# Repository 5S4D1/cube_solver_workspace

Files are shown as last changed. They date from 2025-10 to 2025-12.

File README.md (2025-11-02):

# Rubik's Cube Solver Robot






An automated Rubik's Cube solving system that uses computer vision for color detection, the Kociemba algorithm for solving, and ROS2 for robot control. The system features a web-based interface for capturing cube faces via camera and real-time solution publishing to hardware controllers.

---

## 📋 Table of Contents

- [Features](#-features)
- [System Architecture](#-system-architecture)
- [Hardware Setup](#-hardware-setup)
- [Project Structure](#-project-structure)
- [Installation](#-installation)
- [Usage](#-usage)
- [API Documentation](#-api-documentation)
- [ROS2 Integration](#-ros2-integration)
- [Development](#-development)
- [Troubleshooting](#-troubleshooting)
- [Contributing](#-contributing)
- [License](#-license)
- [Acknowledgments](#-acknowledgments)

---

## ✨ Features

- **🎥 Computer Vision-Based Detection**
  - HSV-based color detection optimized for cubes with black bases
  - Real-time preview with annotated sticker detection
  - Manual color correction interface

- **🧮 Fast Solving Algorithm**
  - Kociemba two-phase algorithm implementation
  - Optimal or near-optimal solutions (typically 20-25 moves)
  - Validates cube state before solving

- **🌐 Web Interface**
  - Mobile-friendly responsive design
  - Camera access for direct cube capture
  - Face-by-face upload workflow
  - Live solution visualization

- **🤖 ROS2 Integration**
  - Real-time solution publishing to `/cube_solution` topic
  - Compatible with ROS2 Humble and newer
  - Separate hardware control node for robot actuation

- **📊 Project Assets**
  - 3D printable robot parts (STL/STEP files)
  - Project reports and documentation
  - Setup images and diagrams

---

## 🏗️ System Architecture

### Block Diagram

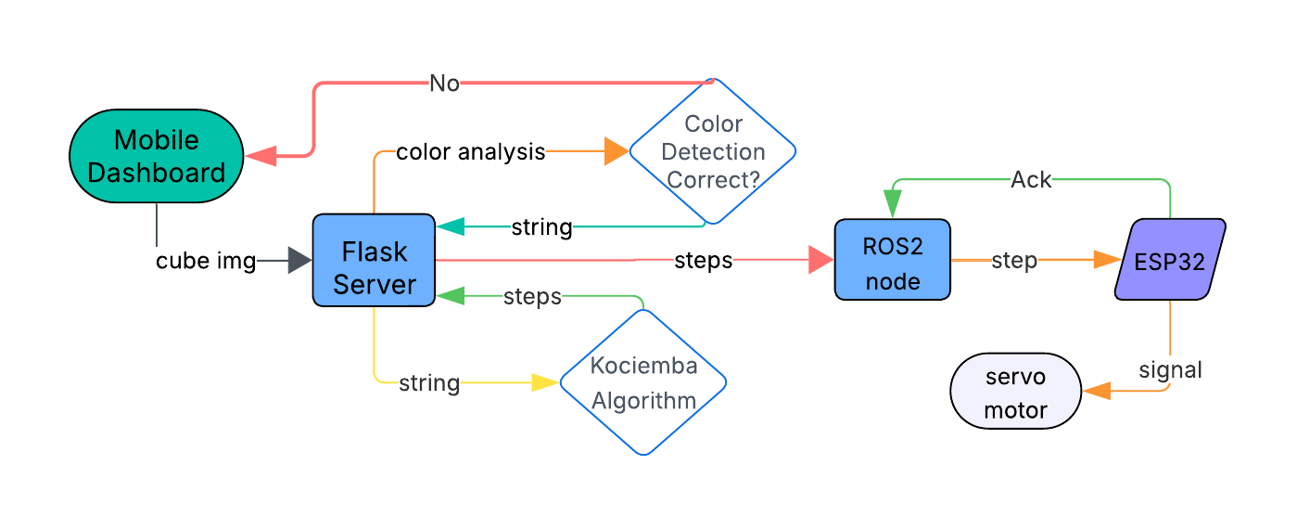
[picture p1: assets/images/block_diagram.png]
System Architecture


### Component Overview

```
┌─────────────────────────────────────────────────────────────┐
│                        Web Browser                          │
│                     (Frontend UI)                           │
│              Camera → Upload → Preview → Solve              │
└────────────────────────┬────────────────────────────────────┘
                         │ HTTPS (Port 5000)
                         ▼
┌─────────────────────────────────────────────────────────────┐
│                    Flask Backend (app.py)                   │
│  ┌──────────────┐  ┌──────────────┐  ┌─────────────────┐  │
│  │   Color      │  │  Kociemba    │  │   ROS2 Bridge   │  │
│  │  Detector    │→ │   Solver     │→ │   Publisher     │  │
│  └──────────────┘  └──────────────┘  └─────────────────┘  │
└────────────────────────────────────────────┬────────────────┘
                                             │ ROS2 Topic
                                             ▼
┌─────────────────────────────────────────────────────────────┐
│              ROS2 /cube_solution Topic                      │
│                   (std_msgs/String)                         │
└────────────────────────────┬────────────────────────────────┘
                             │
                             ▼
┌─────────────────────────────────────────────────────────────┐
│            Hardware Controller Node (Optional)              │
│         Translates moves → Motor commands → Robot           │
└─────────────────────────────────────────────────────────────┘
```

### Technology Stack

| Layer | Technology |
|---|---|
| **Frontend** | HTML5, CSS3, Vanilla JavaScript |
| **Backend** | Python 3.8+, Flask 2.0+ |
| **Computer Vision** | OpenCV, NumPy |
| **Solver** | Kociemba Algorithm (python library) |
| **Middleware** | ROS2 Humble (rclpy, std_msgs) |
| **Hardware** | Arduino (cube_controller firmware) |

---

## 🔧 Hardware Setup

### Physical Setup

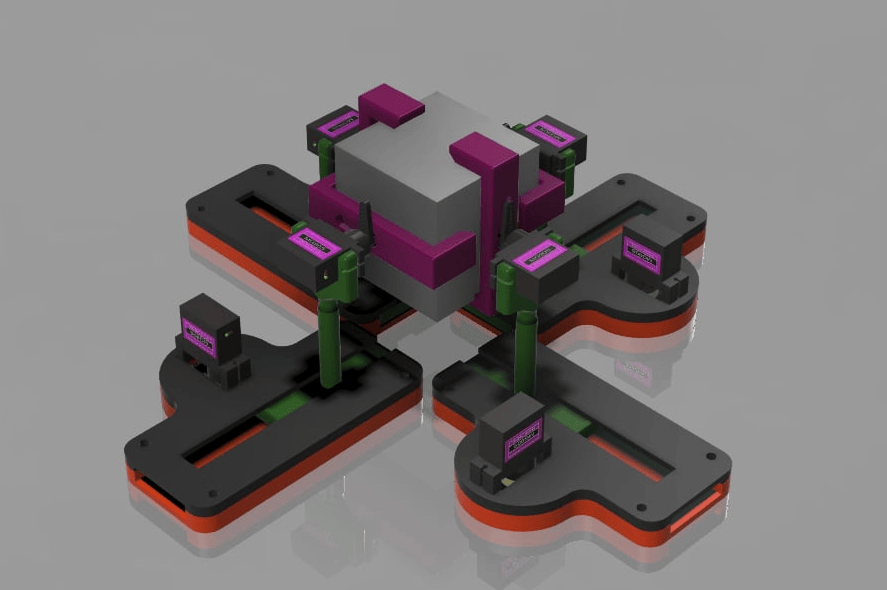
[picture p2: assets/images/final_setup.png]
Final Setup


### Components Required

- **Microcontroller:** Arduino Uno/Mega or compatible board
- **Motors:** 6× Servo motors or stepper motors for face rotation
- **Structure:** 3D-printed frame (files in `assets/3d_parts/`)
- **Camera:** Any USB/built-in camera or smartphone
- **Power Supply:** 5V/12V depending on motor specifications
- **Wiring:** Jumper wires, breadboard, motor drivers (if using steppers)

### 3D Printed Parts

All mechanical parts are available in `assets/3d_parts/`:
- Motor mounts
- Cube holder frame
- Gripper mechanisms
- Base plate

Print settings: 0.2mm layer height, 20% infill, PLA or PETG material.

---

## 📁 Project Structure

```
cube_solver_workspace/
├── assets/                      # Project assets
│   ├── 3d_parts/               # 3D models (STL, STEP)
│   ├── images/                 # Project images and diagrams
│   │   ├── block_diagram.png
│   │   └── final_setup.png
│   └── reports/                # Documentation and reports
├── backend/                     # Flask web server
│   ├── app.py                  # Main Flask application
│   ├── color_detector.py       # Computer vision module
│   ├── kociemba_utils.py       # Cube solver wrapper
│   ├── requirements.txt        # Python dependencies
│   └── uploads/                # Uploaded face images
├── docs/                        # Documentation
│   ├── app.md                  # Backend API documentation
│   ├── color_detector.md       # Color detection module docs
│   ├── kociemba_utils.md       # Solver module docs
│   └── cube_solver_node.md     # ROS2 node documentation
├── firmware/                    # Arduino firmware
│   └── cube_controller/
│       └── cube_controller.ino # Motor control code
├── frontend/                    # Web interface
│   ├── index.html              # Main landing page
│   ├── upload.html             # Face upload interface
│   ├── css/
│   │   └── style.css
│   └── js/
│       └── main.js
├── src/                         # ROS2 package
│   └── cube_solver/
│       ├── package.xml
│       ├── setup.py
│       └── cube_solver/        # ROS2 Python nodes
└── README.md                    # This file
```

---

## 🚀 Installation

### Prerequisites

- **Operating System:** Ubuntu 22.04 (recommended) or compatible Linux
- **Python:** 3.8 or higher
- **ROS2:** Humble Hawksbill or newer
- **Node.js:** Optional (for frontend development tools)

### Step 1: Clone Repository

```bash
git clone https://github.com/5S4D1/cube_solver_workspace.git
cd cube_solver_workspace
```

### Step 2: Install System Dependencies

```bash
# Update system packages
sudo apt update && sudo apt upgrade -y

# Install Python and pip
sudo apt install python3 python3-pip -y

# Install OpenCV dependencies
sudo apt install libopencv-dev python3-opencv -y

# Install ROS2 Humble (if not already installed)
# Follow: https://docs.ros.org/en/humble/Installation.html
```

### Step 3: Install Python Dependencies

```bash
cd backend
pip install -r requirements.txt
```

**requirements.txt includes:**
```
flask>=2.0.0
flask-cors>=3.0.0
kociemba>=1.2.0
opencv-python>=4.5.0
numpy>=1.21.0
pyopenssl>=21.0.0
rclpy
```

### Step 4: Source ROS2 Environment

```bash
source /opt/ros/humble/setup.bash
```

Add to your `~/.bashrc` for persistence:
```bash
echo "source /opt/ros/humble/setup.bash" >> ~/.bashrc
```

### Step 5: Build ROS2 Package (Optional)

If you plan to use the ROS2 subscriber node:

```bash
cd ~/cube_solver_workspace
colcon build --packages-select cube_solver
source install/setup.bash
```

### Step 6: Upload Arduino Firmware (If Using Hardware)

1. Open `firmware/cube_controller/cube_controller.ino` in Arduino IDE
2. Connect your Arduino board
3. Select the correct board and port
4. Upload the firmware

---

## 🎯 Usage

### Quick Start

#### 1. Start the Flask Server

```bash
cd backend
python app.py
```

Server will start at `https://0.0.0.0:5000`

**Note:** HTTPS is required for camera access. You'll see a self-signed certificate warning — accept it to proceed.

#### 2. Access Web Interface

Open your browser and navigate to:
```
https://<your-ip-address>:5000
```

Or on the same machine:
```
https://localhost:5000
```

#### 3. Capture Cube Faces

1. Click "Upload Cube Faces" or navigate to `/upload.html`
2. For each face (U, R, F, D, L, B):
   - Use camera to capture the face
   - Ensure good lighting and center the cube
   - Upload the image
3. Review detected colors (shown with overlays)
4. Manually correct any misdetected colors if needed

#### 4. Solve the Cube

1. Click "Solve Cube" button
2. Backend will:
   - Detect all face colors
   - Validate cube state
   - Compute optimal solution
   - Publish to ROS2 `/cube_solution` topic
3. View solution moves on screen

#### 5. Execute Solution (With Hardware)

If you have the robot hardware connected:
- The solution is automatically published to ROS2
- Your hardware controller node receives the moves
- Robot executes the solution

---

## 📚 API Documentation

### Core Endpoints

| Endpoint | Method | Description |
|---|---|---|
| `/` | GET | Serve main landing page |
| `/upload_face` | POST | Upload single face image |
| `/get_detected_colors?face=U` | GET | Get 3×3 color grid for a face |
| `/solve_cube` | POST | Run full detection → solve → publish pipeline |
| `/manual_solve` | POST | Submit corrected colors or custom cube string |
| `/publish_solution` | POST | Directly solve and publish a cube string |

### Example: Manual Solve with cURL

```bash
curl -X POST https://localhost:5000/manual_solve \
  -H "Content-Type: application/json" \
  -d '{
    "cube_string": "UUUUUUUUURRRRRRRRFFFFFFFFFDDDDDDDDDLLLLLLLLLBBBBBBBBB"
  }'
```

**Response:**
```json
{
  "status": "success",
  "solution": "R U R' U' F2 D B' L2 ..."
}
```

For complete API documentation, see [`docs/app.md`](docs/app.md).

---

## 🤖 ROS2 Integration

### Published Topics

| Topic | Type | Description |
|---|---|---|
| `/cube_solution` | `std_msgs/String` | Solution move sequence (e.g., "R U R' U'") |

### Subscribing to Solutions

Create a simple subscriber:

```python
import rclpy
from rclpy.node import Node
from std_msgs.msg import String

class SolutionListener(Node):
    def __init__(self):
        super().__init__('solution_listener')
        self.subscription = self.create_subscription(
            String,
            '/cube_solution',
            self.solution_callback,
            10)

    def solution_callback(self, msg):
        self.get_logger().info(f'Received solution: {msg.data}')
        # Parse and execute moves here

def main():
    rclpy.init()
    node = SolutionListener()
    rclpy.spin(node)
    node.destroy_node()
    rclpy.shutdown()

if __name__ == '__main__':
    main()
```

Run:
```bash
python3 solution_listener.py
```

For ROS2 node details, see [`docs/cube_solver_node.md`](docs/cube_solver_node.md).

---

## 🛠️ Development

### Running Tests

```bash
# Backend unit tests
cd backend
pytest test_solver.py

# Color detector tests
pytest test_color_detector.py
```

### Adding New Features

1. **Backend:** Add routes to `backend/app.py`
2. **Frontend:** Modify `frontend/index.html` or `frontend/js/main.js`
3. **Computer Vision:** Tune HSV ranges in `backend/color_detector.py`
4. **ROS2:** Add nodes to `src/cube_solver/cube_solver/`

### Logging

Enable debug logging:

```python
import logging
logging.basicConfig(level=logging.DEBUG)
```

Or configure in your application before importing modules:

```python
logging.getLogger('backend.color_detector').setLevel(logging.DEBUG)
```

---

## 🐛 Troubleshooting

### Issue: Camera not accessible in browser

**Solution:** Ensure you're accessing the site via HTTPS (not HTTP). Modern browsers require secure context for camera access.

---

### Issue: "Invalid cube state" error

**Cause:** Detected colors don't form a valid solvable cube.

**Solutions:**
- Check detected colors using annotated `*_detected.jpg` images in `backend/uploads/`
- Improve lighting conditions
- Use manual correction via `/manual_solve` endpoint
- Ensure each color appears exactly 9 times in the 54-sticker cube

---

### Issue: ROS2 topic not receiving messages

**Checklist:**
1. Ensure ROS2 is sourced: `source /opt/ros/humble/setup.bash`
2. Check topic exists: `ros2 topic list`
3. Echo the topic: `ros2 topic echo /cube_solution`
4. Verify Flask backend doesn't show ROS2 errors in console

---

### Issue: Self-signed certificate warnings

**Solution for Development:**
Accept the warning in your browser, or generate a trusted local certificate:

```bash
# Using mkcert (install from https://github.com/FiloSottile/mkcert)
mkcert -install
mkcert localhost 127.0.0.1 ::1
```

Then modify `app.py` to use the generated certificates:
```python
app.run(host='0.0.0.0', port=5000, debug=True, 
        ssl_context=('localhost+2.pem', 'localhost+2-key.pem'))
```

---

### Issue: Colors detected incorrectly (red vs orange, white vs yellow)

**Solutions:**
- Adjust HSV ranges in `color_detector.py` (`HSV_RANGES` dictionary)
- Improve lighting (diffuse white light recommended)
- Ensure cube is centered in frame
- Use manual color correction feature in frontend

See [`docs/color_detector.md`](docs/color_detector.md) for HSV tuning guide.

---

## 📖 Documentation

Detailed documentation for each component:

- **[Backend API (app.py)](docs/app.md)** — Complete API reference, deployment guide
- **[Color Detection (color_detector.py)](docs/color_detector.md)** — Computer vision implementation, HSV tuning
- **[Cube Solver (kociemba_utils.py)](docs/kociemba_utils.md)** — Solver wrapper, algorithm details
- **[ROS2 Node (cube_solver_node)](docs/cube_solver_node.md)** — Hardware integration, node setup

---

## 🤝 Contributing

We welcome contributions! Here's how you can help:

1. **Fork the repository**
2. **Create a feature branch:** `git checkout -b feature/my-new-feature`
3. **Make your changes** and add tests
4. **Update documentation** if needed
5. **Commit your changes:** `git commit -am 'Add new feature'`
6. **Push to the branch:** `git push origin feature/my-new-feature`
7. **Submit a Pull Request**

### Code Style

- **Python:** Follow PEP 8, use `black` formatter
- **JavaScript:** Use ES6+, consistent indentation
- **Documentation:** Update relevant `.md` files in `docs/`

---

## 📄 License

This project is licensed under the MIT License - see the [LICENSE](LICENSE) file for details.

---

## 🙏 Acknowledgments

- **Kociemba Algorithm:** Herbert Kociemba for the two-phase cube solving algorithm
- **Python Kociemba Library:** [kociemba on PyPI](https://pypi.org/project/kociemba/)
- **OpenCV Community:** For computer vision tools and resources
- **ROS2 Community:** For robotics middleware and documentation
- **Contributors:** Thank you to all who have contributed to this project!

---

## 📬 Contact

**Maintainer:** Sadi  
**Email:** shaklinesadi045@gmail.com  
**Repository:** [github.com/5S4D1/cube_solver_workspace](https://github.com/5S4D1/cube_solver_workspace)

---

## 🔗 Quick Links

- [Installation Guide](#-installation)
- [Usage Instructions](#-usage)
- [API Documentation](docs/app.md)
- [Troubleshooting](#-troubleshooting)
- [3D Parts](assets/3d_parts/)
- [Project Reports](assets/reports/)

---

**⭐ If you find this project useful, please star the repository!**

---

*Last Updated: November 2025*

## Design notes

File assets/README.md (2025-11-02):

Project assets

This folder holds project assets used by the frontend and for project delivery.

Structure

- 3d_parts/   - Store 3D design files STL format. Keep original source files here.
- reports/    - Store project reports, PDFs, and documentation artifacts.
- images/     - Store images used in the project and documentation.

Guidelines

- Prefer descriptive filenames: e.g. `clamp.stl`, `Rubik_s_Cube.pdf`, `block_diagram.png`.

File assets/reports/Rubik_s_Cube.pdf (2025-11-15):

3×3 Rubik’s Cube Solver Using Computer Vision,

# ROS2 and ESP32 Controlled Mechanism

Md. Sheikh Sadi
Computer Science and Engineering United International University Dhaka, Bangladesh
msadi223646@bscse.uiu.ac.bd

Badhon Dalbot
Computer Science and Engineering United International University Dhaka, Bangladesh
bdalbot223660@bscse.uiu.ac.bd

Mominul Islam
Computer Science and Engineering United International University Dhaka, Bangladesh
mislam223425@bscse.uiu.ac.bd

Sayed Hasan Sami
Computer Science and Engineering United International University Dhaka, Bangladesh
ssami2230939@bscse.uiu.ac.bd

Md. Mahmud Hasan
Computer Science and Engineering United International University Dhaka, Bangladesh
mhasan2230995@bscse.uiu.ac.bd

Abstract—This paper presents an automated system for solving a standard 3×3 Rubik’s Cube using a combination of computer vision, robotics middleware and a custom mechanical mechanism. The system captures cube face colors with a mobile/web interface, computes an optimal solution using the Kociemba algorithm, and actuates eight servo motors via an ESP32 to manipulate the cube-all coordinated via ROS2. Experimental results demonstrate complete cube solves within ∼96 s, with 98% color detection accuracy in various lighting conditions.
Index Terms—Rubik’s Cube solver, ROS2, ESP32, computer vision, 3D printed mechanism, Kociemba algorithm
I. INTRODUCTION
Problem Statement. Solving a 3×3 Rubik’s Cube quickly and automatically remains a challenging task that combines computer vision, planning algorithms and precise robotic manipulation. Manual solving is accessible, but reliable automation requires robust color detection, efficient solution computation and well-synchronized actuation. Literature Review. Prior work includes robotic cube solvers using stepper motors and simple webcam setups [1], [2]. Some systems rely on dedicated microcontrollers and proprietary drivers [3]. These often trade off modularity or network-based control in favor of pure hardware speed. Innovative features added to our project. Our implementation integrates a mobile/web front-end (for image capture) with the ROS2 middleware, enabling the cube to be manipulated via a publish-subscribe architecture. We also employ an ESP32 controlling eight MG90 servo motors and a fully 3D-printed rack & clamp mechanism-offering cost-effective, scalable hardware.

II. PROPOSED METHOD
A. Block diagram of the overall system
The system comprises three major layers: the user interface (mobile or web), the backend computing & ROS2 broker,

The project was carried out as part of the microprocessor & microcontroller lab course requirement in the Department of Computer Science and Engineering at United International University.

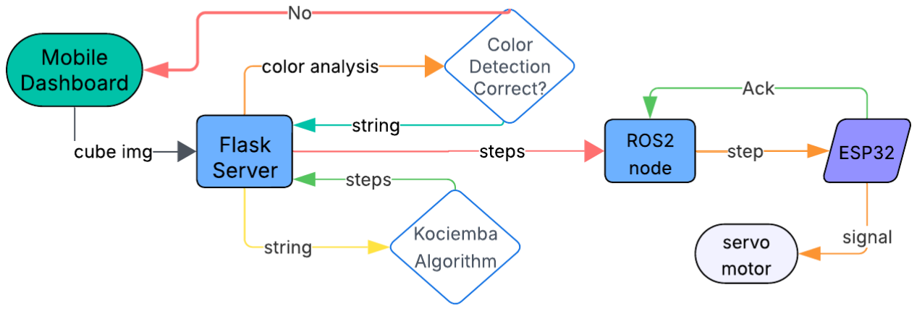
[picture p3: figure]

Fig. 1. Block diagram of the automated cube solving system.

and the mechanical actuation layer. The UI captures six cube faces, the backend uses OpenCV to detect sticker colors and computes a solution via the Kociemba algorithm. That solution is published on a ROS2 topic, subscribed by a node running on a laptop. The laptop forwards individual moves serially to the ESP32, which triggers eight servo motors to manipulate the cube via a 3D-printed rack, clamp and gear system.

III. IMPLEMENTED HARDWARE SYSTEM

A. List of the hardware and software environment

Hardware: ESP32 microcontroller, eight MG90S 9 g servo motors, 3 D-printed parts including rack, rack top, clamp, rack base and spur gear assembly, standard 3×3 Rubik’s Cube. Software: Ubuntu 22.04 LTS with ROS2 Humble, Python 3.13, Flask (backend), OpenCV, Kociemba cube solver library, Web frontend using HTML, CSS, JavaScript.

B. Figures of the implemented hardware system
C. Configure Tables

Table I presents the hardware specifications used in the project, while Table II shows the HSV color detection thresholds used to identify each sticker color during cube face recognition.

Fig. 2. Left: rack. Center: servo holder Right: clamp cube holder.

Fig. 3. Left: rack top. Center: rack base. Right: spur gear

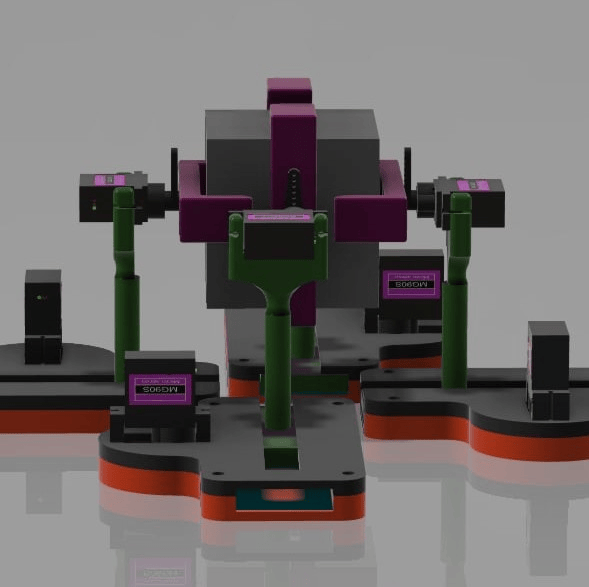
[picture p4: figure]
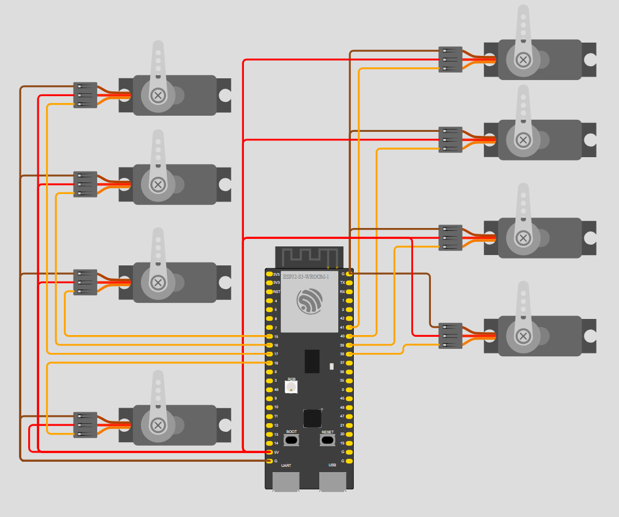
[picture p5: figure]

Fig. 4. Left: MG90S servo mounted on position. Right: ESP32 and wiring interface.


Fig. 5. final setup

TABLE I
SERVO MOTOR AND HARDWARE SPECIFICATIONS
Component | Specification | Value
Servo Type | MG90S Micro-Servo | 9 g, 180◦ range
Microcontroller | ESP32 | Dual-core, WiFi/Bluetooth
3D Printed Parts | Material | PLA+, custom rack, spur and clamp design

TABLE II
HSV COLOR DETECTION RANGES FOR EACH CUBE FACE
Side / Color | Lower HSV Range | Upper HSV Range
White | (0, 0, 120) | (180, 50, 255)
Yellow | (20, 50, 80) | (35, 255, 255)
Red (1) | (0, 120, 120) | (8, 255, 255)
Red (2) | (165, 120, 120) | (180, 255, 255)
Orange | (8, 100, 100) | (25, 255, 255)
Green | (40, 50, 50) | (85, 255, 255)
Blue | (90, 50, 50) | (130, 255, 255)
Black | (0, 0, 0) | (180, 255, 80)

The HSV values in Table II were calibrated manually under controlled lighting conditions. The ranges allow reliable separation of similar hues (e.g., red and orange) and maintain stability across different brightness levels.

IV. RESULTS

The system was evaluated by capturing 20 random cube configurations under varying lighting and executing the full solve sequence. Color detection achieved an average accuracy of 98.2%, and the full mechanical solve completed in 85-110 s depending on re-grip frequency. Table III summarizes the key performance metrics.

TABLE III
PERFORMANCE SUMMARY OF RUBIK’S CUBE SOLVER
Metric | Result
Average Color Detection Accuracy Average Solve Time Fastest Solve Time Slowest Solve Time ROS2–ESP32 Communication Delay Servo Motor Positioning Error | 98.2% 96.4 s 85 s 110 s ≈ 8.7 ms ◦ ±3.8

The system demonstrated reliable communication and consistent solving accuracy even under moderate lighting variations.

V. DISCUSSION

The project demonstrates a cost-effective and modular approach to automated cube solving. However, limitations include the latency of sequential servos ( 90◦
rotations followed
by 180◦ doubling) and physical tolerance in the 3D-printed parts which cause ±2
- mis-alignment. Alternative designs could employ stepper motors or continuous servo systems to reduce repositioning latency (P3). From an ethical viewpoint, the system uses open-source software and reused electronic components, aligning with sustainable design practices (P5). The hardware and software layers are decoupled via ROS2 topics, but they remain inter-dependent when timing constraints require hardware state to be communicated (P7).

P1 | P2 | P3 | P4 | P5 | P6 | P7
✓ | | ✓ | ✓ | ✓ | | ✓

TABLE IV
COMPLEX ENGINEERING PROBLEM MAPPING.

VI. CONCLUSION
This project presents an integrated hardware-software system capable of solving a standard 3×3 Rubik’s Cube automatically. The system achieved high color-detection accuracy and reliable mechanical performance. In future work we plan to incorporate parallel actuation of multiple faces and explore machine-learning-based sticker detection to adapt to more cubes and lighting conditions.

ACKNOWLEDGMENT
The authors would like to express their sincere gratitude to the course faculty of the Department of Computer Science and Engineering, United International University, for their continuous guidance, supervision, and encouragement throughout the project. Special thanks are also extended to the UMRT members for their assistance with fabrication support.

REFERENCES

[1] M. Hoffmann, “Cube Explorer - Optimal Solver for Rubik’s Cube,” 2021. [Online]. Available: https://kociemba.org/cube.htm
[2] A. Kociemba, “Two-Phase Algorithm for Rubik’s Cube,” 2025. [Online]. Available: https://www.jaapsch.net/puzzles/cubic3.htm
[3] J. T. Tørresen and J. E. Gustavsen, “Rubik’s Cube Solving Robot with Computer Vision and Kociemba Algorithm,” in Proc. IEEE Int. Conf. Mechatronics and Automation, 2017, pp. 134–139.
[4] S. P. Rohith, A. C. Varghese, J. Thomas, and M. M. Mathew, “Autonomous Rubik’s Cube Solver Bot,” Int. J. of Scientific Research and Engineering Development, vol. 2, no. 3, pp. 1–6, 2019. [Online]. Available: https://www.academia.edu/41627834/Autonomous Rubiks Cube Solver Bot (https://www.academia.edu/41627834/Autonomous_Rubiks_Cube_Solver_Bot)
[5] S. Sadi, B. Dalbot, S. H. Sami, M. Hasan, and M. Islam, “GitHub Repository of Project Source Code,” GitHub, 2025. [Online]. Available: https://github.com/5S4D1/cube solver workspace (https://github.com/5S4D1/cube_solver_workspace)

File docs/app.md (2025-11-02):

# Flask Backend API Documentation (app.py)

**Version:** 1.0  
**Last Updated:** November 2025  
**Author:** Cube Solver Team

---

## Overview

`backend/app.py` is the core Flask web server that orchestrates the Rubik's Cube solving pipeline. It provides:

- **RESTful API endpoints** for cube image uploads, color detection, and solution computation
- **Static file serving** for the frontend HTML/CSS/JS and assets
- **ROS2 integration** to publish solution move sequences to a `/cube_solution` topic
- **Manual override** for correcting detected colors or submitting custom cube states

The application integrates three key components:
1. **Color detection** (`color_detector.py`) — HSV-based sticker recognition
2. **Cube solver** (`kociemba_utils.py`) — Kociemba two-phase algorithm wrapper
3. **ROS2 publisher** — Real-time messaging to a robot/hardware controller

---

## Architecture

```
┌─────────────────┐
│   Frontend      │ (HTML/CSS/JS served by Flask)
│   (Browser)     │
└────────┬────────┘
         │ HTTP/HTTPS
         ▼
┌─────────────────┐
│   Flask App     │ app.py
│   (Port 5000)   │
└────────┬────────┘
         │
         ├─► color_detector.py  (detect colors from images)
         ├─► kociemba_utils.py  (solve cube string)
         └─► ROS2 /cube_solution topic (publish solution)
```

### Key Design Decisions

- **CORS enabled** for all routes — allows frontend to call API from different origins during development.
- **SSL/HTTPS (adhoc)** — required to access camera from browsers on local network (camera API needs secure context).
- **Per-request ROS2 init/shutdown** — Flask is not ROS2-native, so each publish operation initializes and shuts down `rclpy` to avoid threading conflicts.
- **File-based storage** — uploaded images are saved to `backend/uploads/` with standardized filenames (`U.jpg`, `R.jpg`, etc.) to simplify face-by-face detection.

---

## Configuration

### Environment Variables (Optional)

| Variable | Default | Description |
|---|---|---|
| `UPLOAD_FOLDER` | `uploads` | Directory for uploaded and annotated images  |
| `FRONTEND_FOLDER` | `../frontend` | Path to static HTML/CSS/JS frontend files |

### Flask Configuration

- **Host:** `0.0.0.0` (listens on all interfaces)
- **Port:** `5000`
- **Debug Mode:** `True` (disable in production)
- **SSL Context:** `adhoc` (self-signed cert for HTTPS; install `pyopenssl` if missing)

---

## API Reference

### Static File Serving

#### `GET /`
**Description:** Serve the main landing page.

**Response:** `frontend/index.html`

---

#### `GET /upload.html`
**Description:** Serve the face upload page.

**Response:** `frontend/upload.html`

---

#### `GET /js/<path:filename>`
**Description:** Serve JavaScript files from `frontend/js/`.

**Example:** `/js/main.js`

---

#### `GET /css/<path:filename>`
**Description:** Serve CSS stylesheets from `frontend/css/`.

**Example:** `/css/style.css`

---

#### `GET /assets/<path:filename>`
**Description:** Serve assets (3D models, reports, images) from `frontend/assets/`.

**Example:** `/assets/images/demo.jpg`

---

#### `GET /uploads/<path:filename>`
**Description:** Serve uploaded or detected images from `backend/uploads/`.

**Example:** `/uploads/U_detected.jpg` (annotated detection image)

---

### Cube Solving Workflow

#### `POST /upload_face`
**Description:** Upload a single face image. The frontend should call this endpoint six times (once per face: U, R, F, D, L, B).

**Request:**
- **Content-Type:** `multipart/form-data`
- **Form Fields:**
  - `file` (file): Image file (JPEG/PNG)
  - `face` (string): Face identifier — one of `U`, `R`, `F`, `D`, `L`, `B`

**Response:**
```json
{
  "status": "success",
  "face": "U",
  "filename": "U.jpg"
}
```

**Errors:**
- `400` — Missing `file` or `face`, or invalid face identifier
- `500` — File save error

**Storage:** Image is saved as `backend/uploads/<FACE>.jpg` (overwrites previous uploads).

---

#### `GET /get_detected_colors?face=<FACE>`
**Description:** Detect and return the 3×3 color grid for a specific face. Also generates an annotated image (`<FACE>_detected.jpg`) showing detected colors overlaid on the original.

**Query Parameters:**
- `face` (string, required): Face identifier (`U`, `R`, `F`, `D`, `L`, `B`)

**Response:**
```json
{
  "colors": [
    ["U", "U", "U"],
    ["U", "U", "U"],
    ["U", "U", "U"]
  ]
}
```

**Errors:**
- `400` — Invalid face parameter
- `404` — Image `<FACE>.jpg` not found in `uploads/`
- `500` — Color detection error

**Side Effects:** Writes `backend/uploads/<FACE>_detected.jpg` (annotated image used by frontend preview).

**Implementation Details:**
- Calls `detect_face_colors(image_path, save_path)` from `color_detector.py`
- Returns a 3×3 nested list (row-major order)
- Each color is a single-character Kociemba notation letter: `U`, `R`, `F`, `D`, `L`, `B`, or `X` (unknown)

---

#### `POST /solve_cube`
**Description:** Execute the full pipeline: detect all six faces → assemble cube string → solve → publish to ROS2.

**Request:**
- **Content-Type:** `application/json` (body can be empty)
- **Precondition:** All six face images (`U.jpg`, `R.jpg`, `F.jpg`, `D.jpg`, `L.jpg`, `B.jpg`) must exist in `backend/uploads/`.

**Response (Success):**
```json
{
  "status": "success",
  "solution": "R U R' U' F2 D B' ..."
}
```

**Response (Error):**
```json
{
  "status": "error",
  "message": "Invalid cube state"
}
```

**Flow:**
1. Call `get_cube_string()` → detects colors from all six images and assembles 54-character cube string
2. Call `solve_cube(cube_string)` → computes solution using Kociemba algorithm
3. Publish solution to ROS2 topic `/cube_solution` (message type: `std_msgs/String`)
4. Return solution to client

**Errors:**
- `500` — Missing images, invalid cube state, or ROS2 publish failure

**Notes:**
- This endpoint initializes and shuts down `rclpy` per request (safe for Flask single-threaded mode).
- If ROS2 is not running or the topic has no subscribers, publish still succeeds (fire-and-forget).

---

#### `POST /publish_solution`
**Description:** Accept a pre-computed cube string, solve it, and publish the solution to ROS2. Useful for testing or when cube state is provided manually.

**Request:**
```json
{
  "cube_string": "UUUUUUUUURRRRRRRRFFFFFFFFFDDDDDDDDDLLLLLLLLLBBBBBBBBB"
}
```

**Response (Success):**
```json
{
  "status": "success",
  "solution": "R U R' U' ..."
}
```

**Response (Error):**
```json
{
  "status": "error",
  "message": "cube_string is required"
}
```

**Validation:**
- `cube_string` must be exactly 54 characters
- Must represent a valid, solvable cube state (Kociemba will raise exception otherwise)

**Flow:**
1. Extract `cube_string` from request JSON
2. Call `solve_cube(cube_string)`
3. Publish solution to `/cube_solution` ROS2 topic
4. Return solution

---

#### `POST /manual_solve`
**Description:** Advanced endpoint for submitting corrected or manually entered cube states. Accepts either a direct 54-character cube string OR a structured JSON object with per-face 3×3 grids.

**Request Format A (Direct Cube String):**
```json
{
  "cube_string": "UUUUUUUUURRRRRRRRFFFFFFFFFDDDDDDDDDLLLLLLLLLBBBBBBBBB"
}
```

**Request Format B (Per-Face Grids):**
```json
{
  "U": [["U","U","U"], ["U","U","U"], ["U","U","U"]],
  "R": [["R","R","R"], ["R","R","R"], ["R","R","R"]],
  "F": [["F","F","F"], ["F","F","F"], ["F","F","F"]],
  "D": [["D","D","D"], ["D","D","D"], ["D","D","D"]],
  "L": [["L","L","L"], ["L","L","L"], ["L","L","L"]],
  "B": [["B","B","B"], ["B","B","B"], ["B","B","B"]]
}
```

**Response (Success):**
```json
{
  "status": "success",
  "solution": "R U R' U' F2 ..."
}
```

**Response (Error):**
```json
{
  "error": "missing face U in JSON",
  "solution": "Invalid cube state"
}
```

**Validation:**
- Format A: `cube_string` must be 54 characters
- Format B: All six faces (`U`, `R`, `F`, `D`, `L`, `B`) must be present; each must be a 3×3 array of single-character strings

**Flow:**
1. Parse JSON and construct 54-character cube string
2. Call `solve_cube(cube_string)`
3. Call `publish_solution(solution)` → publishes to ROS2
4. Return solution

**Use Cases:**
- Frontend "manual correction" UI where user edits detected colors
- Testing with known cube states
- Integration with external color detection systems

---

## Helper Functions

### `publish_solution(solution: str)`
**Description:** Internal helper to publish a solution string to the ROS2 `/cube_solution` topic.

**Parameters:**
- `solution` (str): Move sequence (e.g., `"R U R' U'"`)

**Behavior:**
- Initializes `rclpy`
- Creates a temporary node `cube_solution_publisher`
- Publishes a `std_msgs/String` message with `data=solution`
- Shuts down `rclpy` (ensures cleanup even on exception)

**Thread Safety:** This pattern is safe for Flask's single-threaded default mode. For production with threading/Gunicorn, consider a persistent ROS2 node in a separate thread or process.

---

## Deployment

### Local Development

1. **Install dependencies:**
   ```bash
   cd backend
   pip install flask flask-cors kociemba opencv-python numpy pyopenssl rclpy std_msgs
   ```

2. **Prepare upload directory:**
   ```bash
   mkdir -p uploads
   ```

3. **Run the server:**
   ```bash
   python app.py
   ```

   Server starts on `https://0.0.0.0:5000` (HTTPS with self-signed cert).

4. **Access frontend:**
   Open `https://<your-ip>:5000/` in a browser. Accept the self-signed certificate warning.

### Production Considerations

- **Disable debug mode:** Set `debug=False` in `app.run()`
- **Use a production WSGI server:** Deploy with Gunicorn or uWSGI instead of Flask's built-in server
  ```bash
  gunicorn --bind 0.0.0.0:5000 --certfile cert.pem --keyfile key.pem app:app
  ```
- **Persistent ROS2 node:** Initialize `rclpy` once at startup and use a background thread/process for publishing to avoid overhead
- **Error handling & logging:** Replace `print()` with proper logging (`logging` module) and add structured error responses
- **Authentication:** Add token-based auth if exposing to public networks
- **Rate limiting:** Use Flask-Limiter to prevent abuse on upload/solve endpoints

### ROS2 Setup

Ensure ROS2 is installed and sourced before running `app.py`:

```bash
source /opt/ros/<distro>/setup.bash  # e.g., humble, foxy
```

Verify the `/cube_solution` topic:
```bash
ros2 topic echo /cube_solution
```

---

## Error Handling

| HTTP Status | Meaning | Common Causes |
|---|---|---|
| `200` | Success | Operation completed successfully |
| `400` | Bad Request | Missing parameters, invalid JSON, bad face |
| `404` | Not Found | Image not uploaded yet |
| `500` | Internal Server Error | Color detection failure, invalid cube |

**Error Response Format:**
```json
{
  "status": "error",
  "message": "Detailed error message",
  "error": "Alternative error field (some endpoints)"
}
```

---

## Example Workflows

### Workflow 1: Full Automated Pipeline

1. User uploads six face images via `POST /upload_face` (U, R, F, D, L, B)
2. Frontend displays detected colors using `GET /get_detected_colors?face=U` (repeat for all faces)
3. User confirms and clicks "Solve"
4. Frontend calls `POST /solve_cube`
5. Backend detects colors, solves, publishes to ROS2, and returns solution
6. Frontend displays solution moves

### Workflow 2: Manual Correction

1. User uploads images and reviews detected colors
2. Frontend detects errors in color detection (e.g., red detected as orange)
3. User edits colors in a correction UI
4. Frontend submits corrected per-face grids to `POST /manual_solve`
5. Backend assembles cube string, solves, publishes, returns solution

### Workflow 3: Direct Testing (Thunder Client / Postman)

1. Prepare a known cube string (54 chars)
2. Send `POST /publish_solution` with JSON: `{"cube_string": "..."}`
3. Observe solution in response and on ROS2 topic `/cube_solution`

---

## Testing

### Unit Tests

Create `backend/test_app.py`:

```python
import pytest
from app import app

@pytest.fixture
def client():
    app.config['TESTING'] = True
    with app.test_client() as client:
        yield client

def test_home(client):
    rv = client.get('/')
    assert rv.status_code == 200

def test_upload_face_missing_params(client):
    rv = client.post('/upload_face')
    assert rv.status_code == 400
    assert b'Missing file or face' in rv.data
```

Run:
```bash
pytest backend/test_app.py
```

### Integration Tests

- Upload test cube images and verify solution matches expected output
- Mock ROS2 publisher to verify messages are published with correct content

---

## Security Notes

- **HTTPS Required:** Camera access requires HTTPS. The server uses `ssl_context='adhoc'` for local dev. Use proper certificates in production.
- **File Upload Validation:** Currently allows any file type. Add MIME type checks and file size limits.
- **Input Sanitization:** Validate `face` parameter and `cube_string` length/format to prevent injection or DoS.
- **CORS Configuration:** In production, restrict CORS to specific origins instead of allowing all (`CORS(app, origins=['https://yourdomain.com'])`).

---

## Troubleshooting

### Issue: "Cannot read image" error

**Cause:** Image file not found or corrupted.

**Solution:** Verify all six face images exist in `backend/uploads/` with correct names (`U.jpg`, `R.jpg`, etc.).

---

### Issue: ROS2 publish fails

**Cause:** ROS2 not sourced or `rclpy` not installed.

**Solution:**
```bash
source /opt/ros/<distro>/setup.bash
pip install rclpy
```

---

### Issue: "Invalid cube state" from solver

**Cause:** Detected colors do not represent a valid, solvable cube (e.g., wrong number of each color, impossible corner/edge positions).

**Solution:**
- Review detected colors using `/get_detected_colors` and `<FACE>_detected.jpg` images
- Use `/manual_solve` to correct misdetected colors
- Improve lighting and image quality during capture

---

### Issue: HTTPS certificate warnings

**Cause:** Self-signed certificate used for local dev.

**Solution:** Accept the warning in browser, or generate a trusted cert using Let's Encrypt or mkcert for local dev.

---

## Related Documentation

- [color_detector.py](./color_detector.md) — Color detection implementation and HSV tuning
- [kociemba_utils.py](./kociemba_utils.md) — Cube solver wrapper
- [cube_solver_node.md](./cube_solver_node.md) — ROS2 node that consumes `/cube_solution` topic

---

## Changelog

| Version | Date | Changes |
|---|---|---|
| 1.0 | Nov 2025 | Initial release with full pipeline and ROS2 pub |

---

## Contributing

When adding new endpoints:
1. Add route handler with docstring describing purpose, request/response formats, and errors
2. Update this documentation with new API reference entry
3. Add unit tests in `backend/test_app.py`
4. Consider logging and error handling for production readiness

---

**Questions or Issues?** Open an issue on the project repository or contact the development team.

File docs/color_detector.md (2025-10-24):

# color_detector.py Documentation

This module contains utilities to detect sticker colours from photos of a 3x3 Rubik's Cube and to assemble those detections into a cube state string compatible with the Kociemba solver.

The implementation is tuned for cubes with a dark/black plastic base and colored stickers, and uses simple HSV thresholds + median sampling to be more robust to highlights and camera noise.

---

## Quick overview

- Main public functions
  - `detect_face_colors(image_path, save_path=None) -> List[str]` — detect the 9 stickers on a single face and optionally write an annotated image with rectangles drawn around sampled stickers.
  - `get_cube_string(upload_folder='uploads') -> dict` — reads six images (U.jpg, R.jpg, F.jpg, D.jpg, L.jpg, B.jpg) from `upload_folder`, annotates and saves detected images (e.g. `U_detected.jpg`) and returns a structured result with per-face detections, an `ok` flag, and any `errors`.

- Helper functions (smaller building blocks)
  - `classify_color(hsv_pixel) -> str` — classifies a single HSV pixel tuple into Kociemba letters `'U','R','F','D','L','B'` or `'X'` for unknown/invalid.
  - `letter_to_bgr(letter) -> Tuple[int,int,int]` — maps Kociemba letters to BGR tuples used when drawing rectangles on annotated images.
  - `in_range(hsv_pixel, hsv_range) -> bool` — low-level helper to compare HSV triplet against a (lower, upper) bound.

---

## Installation / dependencies

color_detector uses OpenCV and NumPy. Install them using pip:

```bash
pip install opencv-python numpy
```

If your project uses `backend/requirements.txt`, make sure it lists `opencv-python` and `numpy`.

---

## Details & behavior

- Input normalization:
  - Input images are read with `cv2.imread()` and resized to 300x300 pixels before processing. This normalizes coordinates and sampling.

- Sticker sampling:
  - Each 3x3 sticker grid cell is sampled at its center. A 10x10 region around the center is taken and the median HSV values are used to reduce specular highlights and outlier pixels.

- HSV-based detection:
  - The module contains a set of tuned HSV ranges (`HSV_RANGES`) for white, yellow, red (split into two hue ranges to handle hue wrap), orange, green, blue, and black (the cube plastic).
  - `classify_color` implements a decision tree combining explicit range checks, heuristic fallbacks, and tie-breakers when pixels match both red and orange ranges. Very dark pixels (low V) are considered `'X'` unknown/invalid (likely cube base or background).

  - Logging: The module uses Python's `logging` module. Debug/diagnostic messages that were previously printed are now emitted via a module-level logger (`logging.getLogger(__name__)`) at `DEBUG` level. When run as a script the final cube string is logged at `INFO` level. Do not configure logging inside this library; configure it in the application or test runner. Example to enable debug output during development:

  ```py
  import logging
  logging.basicConfig(level=logging.DEBUG)
  # or target the module specifically
  logging.getLogger('backend.color_detector').setLevel(logging.DEBUG)
  ```

- Output format:
  - `detect_face_colors` returns a list of 9 single-character strings (letters in Kociemba notation or `'X'`). The order is row-major (top-left to bottom-right).
  - `get_cube_string` returns a dictionary with the following keys:
    - `ok` (bool): True when all six faces were detected successfully.
    - `cube_string` (str|null): the 54-character cube string in Kociemba order `U R F D L B` when `ok` is True, otherwise `null`.
    - `faces` (dict): mapping from face id (`U`,`R`,`F`,`D`,`L`,`B`) to a list of 9 detected letters or `null` if detection failed for that face.
    - `errors` (list): list of per-face error objects with fields `face`, `image`, and `error` (message).

---

## Function reference and examples

detect_face_colors

- Signature: `detect_face_colors(image_path, save_path=None) -> List[str]`
- Input:
  - `image_path` (str): path to a single face image (expects a 3x3 face roughly filling the image after resizing to 300x300).
  - `save_path` (str|None): optional path to write an annotated image showing rectangles and detected colors.
- Output: list of 9 letters, each one of `['U','D','L','R','F','B','X']` (`'X'` = unknown/invalid).
- Errors: raises `ValueError` if the image cannot be read.

Example:

```py
from backend.color_detector import detect_face_colors

colors = detect_face_colors('backend/uploads/U.jpg', save_path='backend/uploads/U_detected.jpg')
print(colors)  # ['U','U','U','U','U','U','U','U','U'] for a solved white face
```

get_cube_string

 - Signature: `get_cube_string(upload_folder='uploads') -> dict`
 - Behavior: looks for files named `U.jpg`, `R.jpg`, `F.jpg`, `D.jpg`, `L.jpg`, `B.jpg` inside `upload_folder`, calls `detect_face_colors` for each, writes annotated `*_detected.jpg` files alongside them, and returns a structured result describing per-face detections and any errors.
 - Errors: per-face errors are captured and returned in the `errors` list rather than being raised; the caller should check the `ok` flag and `errors` to decide whether to retry capturing specific faces.

Example:

```py
from backend.color_detector import get_cube_string

result = get_cube_string('backend/uploads')
if result['ok']:
  print(result['cube_string'])  # 54-character string in URFDLB order
else:
  print('Detection failed for faces:', [e['face'] for e in result['errors']])
```

Note: The function currently hard-codes the `upload_folder` and expects exact filenames; caller code should ensure images exist and are named correctly.

---

## Error modes and diagnostics

- Image read failure: `cv2.imread()` returns `None` -> `ValueError` with a message about not being able to read the image.
 - Unknown/invalid sticker: classifier returns `'X'`. The module emits debug logs when encountering `'X'` or ambiguous red/orange colors. Configure the Python logging system in your application to view these diagnostics (see the example above).

---

## Edge cases, limitations, and recommendations

- Hard-coded sizes and coordinates: the current implementation resizes images to 300x300 and samples centers using fixed offsets. This works well when input images contain a roughly centered face filling most of the frame. For more robust operation, consider detecting the face region dynamically (e.g., using contours or a simple grid detection), or allow the caller to pass pre-aligned/cropped faces.

- Threshold tuning: HSV ranges are tuned for a specific camera lighting and a dark cube; they may require adjustments for different cameras, lighting, or sticker materials. Consider externalizing these ranges to a JSON/YAML config or exposing them as function parameters.

- Ambiguous red vs orange: the code has heuristics (saturation thresholds and hue distance) to break ties. You may still get misclassifications; adding a small calibration step (ask user to provide a single reference image) can dramatically increase accuracy.

- Unknown `'X'`: currently propagated into the 54-char cube string, which will make the Kociemba solver fail. Prefer returning a structured result with a success flag and per-face diagnostics so the caller can request a re-capture in case of `'X'` values.

---

## Tests to add

- Unit tests for `classify_color` with synthetic HSV values covering red/orange tie cases, low-V (black), white (low saturation/high V), and edge hue values.
- Integration tests using the sample images in `backend/uploads` to verify `detect_face_colors` and `get_cube_string` produce expected output. Add these to `backend/test_solver.py` or create a dedicated `test_color_detector.py`.

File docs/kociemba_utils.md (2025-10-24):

# kociemba_utils.py Documentation

This module provides a thin wrapper around the `kociemba` package to solve a 3x3 Rubik's Cube state string using the Kociemba two-phase algorithm.

## Purpose

`kociemba_utils.py` exposes a single convenience function `solve_cube` that:
- Validates a cube string is 54 characters long
- Calls `kociemba.solve(...)` to compute a solution
- Prints and returns the solution string

## Installation

The project depends on the `kociemba` Python package. Install it in your environment:

```bash
pip install kociemba
```

If you install dependencies from `backend/requirements.txt`, ensure `kociemba` is listed there.

## Function API

```py
from kociemba_utils import solve_cube

solution = solve_cube(cube_string)
```

Function: solve_cube(cube_string: str) -> str

- Parameters:
  - `cube_string` -- A 54-character string representing the cube facelets in the Kociemba order (URFDLB). Each character represents the face colour of a sticker (commonly 'U', 'R', 'F', 'D', 'L', 'B').

- Returns:
  - On success: a move-sequence string returned by `kociemba.solve`, e.g. "R U R' U'".
  - On error: the function catches exceptions from `kociemba.solve`, prints the error, and returns the string "Invalid cube state".

- Raises:
  - `ValueError` if `cube_string` is not exactly 54 characters long.

## Cube string format (URFDLB)

Kociemba expects the cube string in the face order: U, R, F, D, L, B — each face provided as 9 characters (row-major). Example solved-cube input:

```
UUUUUUUUURRRRRRRRRFFFFFFFFFDDDDDDDDDLLLLLLLLLBBBBBBBBB
```

Make sure the characters represent a valid cube colouring and that the string uses a consistent character set (e.g. 'U', 'R', 'F', 'D', 'L', 'B' or colour initials). If the colouring/order is wrong, `kociemba.solve` will raise an exception.

## Example usage

```py
from backend.kociemba_utils import solve_cube

# Example: solved cube
solved = 'UUUUUUUUURRRRRRRRRFFFFFFFFFDDDDDDDDDLLLLLLLLLBBBBBBBBB'
print(solve_cube(solved))  # -> typically an empty string or "" (no moves needed)

# Example: invalid length
try:
    solve_cube('too short')
except ValueError as e:
    print(e)
```

### Error handling and suggestions

- The current implementation prints errors and returns a sentinel string `"Invalid cube state"`. Calling code should check for that return value.
- For cleaner error handling in production, consider re-raising the original exception or returning a structured result (e.g., tuple (success: bool, solution_or_error: str)).
- Add logging instead of printing for better observability.

### Edge cases and notes

- Non-54 length: `ValueError` is raised.
- Syntactically correct but impossible cube states: `kociemba.solve` will raise; the wrapper returns "Invalid cube state".
- Input character set: be consistent (don't mix colour names and face letters).

### Tests

There is a `backend/test_solver.py` in this project — extend it with tests covering:
- Correct solved-cube input (expect empty solution or no-move result)
- A known scrambled cube with a determinable solution
- Bad input length -> assert ValueError
- Invalid but 54-length input -> assert the wrapper returns "Invalid cube state" (or update wrapper to raise)

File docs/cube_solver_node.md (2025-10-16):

# Cube Solver Node Documentation

This document describes the `cube_solver_node` from the `cube_solver` ROS 2 package. It covers the node's responsibilities, runtime behavior, public interfaces (topics and parameters), message flow, error handling, deployment, and operational guidance.

## Overview

`cube_solver_node` bridges a high-level Rubik’s Cube solution (as a sequence of moves) to a hardware controller (ESP32) over a serial connection. It subscribes to a ROS 2 topic that provides the full solution string (e.g., `"R U R' U'"`), relays each move to the ESP32 one-by-one, and waits for an acknowledgment ("DONE") after each move before proceeding. It also publishes each move on a ROS topic for UI/telemetry purposes.

Key capabilities:
- Receive a full solution string via ROS 2
- Parse the solution into individual moves
- Send moves over serial to ESP32 at 115200 baud
- Wait for a per-move acknowledgment with timeout
- Publish each move for dashboards/monitoring
- Log all significant events and error conditions

## Node Identity

- Package: `cube_solver`
- Executable (console script): `cube_solver_node`
- Node name: `cube_solver_node`

## Runtime Dependencies

- ROS 2 (rclpy)
- `std_msgs` (String)
- Python packages: `pyserial`, `time` (stdlib)
- Hardware: ESP32 connected at `/dev/ttyUSB0`

Ensure `pyserial` is installed in the environment. In this repository, Python dependencies for other components live under `backend/requirements.txt`; add `pyserial` there if not present when building a single consolidated environment.

## Topics

- Subscription:
  - Name: `cube_solution`
  - Type: `std_msgs/msg/String`
  - Description: Provides the full cube solution as a space-separated string of moves. Example: `"R U R' U' F2 D"`.

- Publication:
  - Name: `cube_move`
  - Type: `std_msgs/msg/String`
  - Description: Emits each move that is being sent to the ESP32, one message per move. Useful for dashboards or other consumers that visualize progress in real time.

## Serial Protocol

- Port: `/dev/ttyUSB0`
- Baud rate: `115200`
- Timeout (read): `1` second per `serial.Serial` configuration, with an overall per-move wait loop of up to `10` seconds for acknowledgment.
- Outbound message: the move string followed by a newline (`\n`). Example: `b"R\n"`.
- Inbound acknowledgment: the literal string `"DONE"` (without surrounding quotes) indicates successful execution of the move. Any other text is logged at `INFO` level.

If the node cannot open the serial port at startup, it logs an error and continues running; move sending will be skipped with a warning until a serial connection is available (requires restarting the node after fixing the connection).

## Behavior and Flow

1. On startup, the node attempts to open `/dev/ttyUSB0` at 115200 baud. Success is logged. Failure is logged and the node continues, but cannot send moves.
2. When a `cube_solution` message arrives:
   - The string is trimmed and split on whitespace into a list of moves (e.g., `["R", "U", "R'", "U'"]`).
   - For each move in order:
     - The node writes the move to the serial port with a trailing newline.
     - It publishes the same move on `cube_move` for downstream consumers.
     - It polls the serial input buffer for up to 10 seconds. If a line equals `DONE`, the next move is sent. Any other lines are logged. If `DONE` is not received within the timeout, the sequence is aborted.
   - A summary is logged indicating success or early termination.

## Timeout and Error Handling

- Serial connect failure: Logged as an error at startup; the node continues running. Subsequent move attempts immediately warn and return failure.
- Per-move timeout: If `DONE` is not received within 10 seconds after sending a move, the node logs an error and aborts the remaining sequence.
- Serial exceptions: Any exception during write/read is caught, logged as an error, and treated as a failed move, aborting the sequence.
- Keyboard interrupt: Gracefully shuts down, closing the serial port if open.

## Input/Output Contract

- Input: `std_msgs/String` solution where `data` is a space-separated sequence of cube moves expressed in your robot’s move vocabulary. Common tokens might include: `R, L, U, D, F, B, R', L', U', D', F', B', R2, L2, U2, D2, F2, B2`. The node does not validate syntax; it forwards moves as-is.
- Output: For each input move, publishes the same token on `cube_move` immediately after writing to serial.
- Ack requirement: For each move, the ESP32 must eventually send a line `DONE` to allow progression.

## Configuration Notes

- Serial port path: hard-coded to `/dev/ttyUSB0`. If your ESP32 appears elsewhere (e.g., `/dev/ttyACM0`), adjust the code or create a persistent udev rule mapping your board to `/dev/ttyUSB0`.
- Baud rate: 115200. Ensure firmware matches this rate.
- Ack token: `DONE`. Ensure firmware sends exactly this line (case-sensitive, newline-terminated) after each move completes.
- Ack timeout: 10 seconds. Adjust in code if your mechanics are slower.

## Logging

- Connection success: `INFO` (with ✅)
- Connection failure: `ERROR` (with ❌)
- Received solution and parsed move count: `INFO`
- Sent move: `INFO` (with 📤)
- ESP32 log lines: `INFO`
- Ack success: `INFO` (with ✅)
- Ack timeout: `ERROR` (with ❌)
- Missing serial connection when sending: `WARN` (with ⚠️)
- Sequence halted due to missing ACK: `WARN` (with ⚠️)

These symbols aid quick scanning of logs but are optional when scraping logs programmatically.

## Launch and Usage

Build and source the workspace using your ROS 2 toolchain. Then run the node via its console entry point.

Example workflow (assuming the workspace is already built):

- Run the node:
  - `ros2 run cube_solver cube_solver_node`

- Publish a test solution (replace with your actual solution):
  - `ros2 topic pub --once /cube_solution std_msgs/String '{data: "R U R' U' F2"}'`

- Monitor outgoing moves:
  - `ros2 topic echo /cube_move`

Ensure the ESP32 is connected and the firmware is listening on the same serial settings.

## Extensibility Considerations

If you need to extend or adapt the node:
- Parameterize serial settings and ack token using ROS parameters.
- Add input validation for moves to catch malformed tokens early.
- Support a queue or cancellation service to abort a running sequence.
- Provide a service/action interface for better lifecycle management and status reporting.
- Add a retry policy per move before aborting.
- Emit richer telemetry (e.g., timing per move, retries, error codes).

## Source Reference

- File: `src/cube_solver/cube_solver/cube_solver_node.py`
- Entry point: defined in `src/cube_solver/setup.py` under `console_scripts` as `cube_solver_node = cube_solver.cube_solver_node:main`.

## Minimal API Summary

- Class: `CubeSolverNode(Node)`
  - Subscriptions: `cube_solution` (`std_msgs/String`)
  - Publishers: `cube_move` (`std_msgs/String`)
  - Methods:
    - `solution_callback(msg: String) -> None`: Processes an incoming solution string and orchestrates move execution.
    - `send_move_with_ack(move: str) -> bool`: Sends a move to ESP32 and waits up to 10 seconds for an `DONE` acknowledgment.
- Function: `main(args=None) -> None`: Initializes ROS, spins the node, and handles graceful shutdown including closing the serial port.

## Testing Notes

For offline testing without hardware:
- Consider mocking the serial interface (e.g., with `pyserial-asyncio` or a stub that simulates `in_waiting` and `readline()` returning `DONE`).
- You can still observe `cube_move` publications in ROS to verify parsing and sequencing.

---

This document is intended to be a reliable operational reference for developers and operators interacting with the `cube_solver_node`. Update it if the serial protocol, topics, or behavior change.

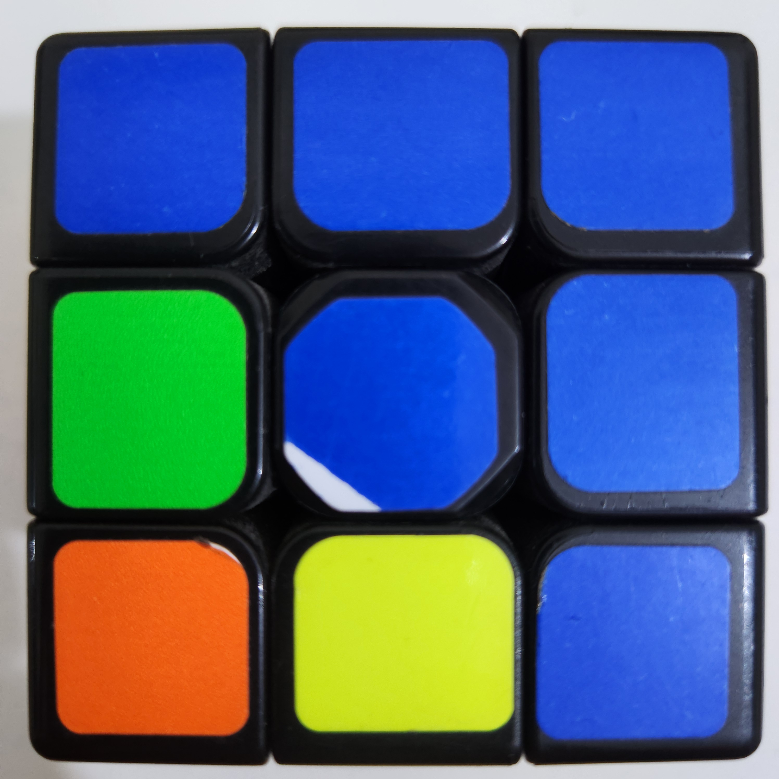
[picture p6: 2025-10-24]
backend/uploads/B.jpg

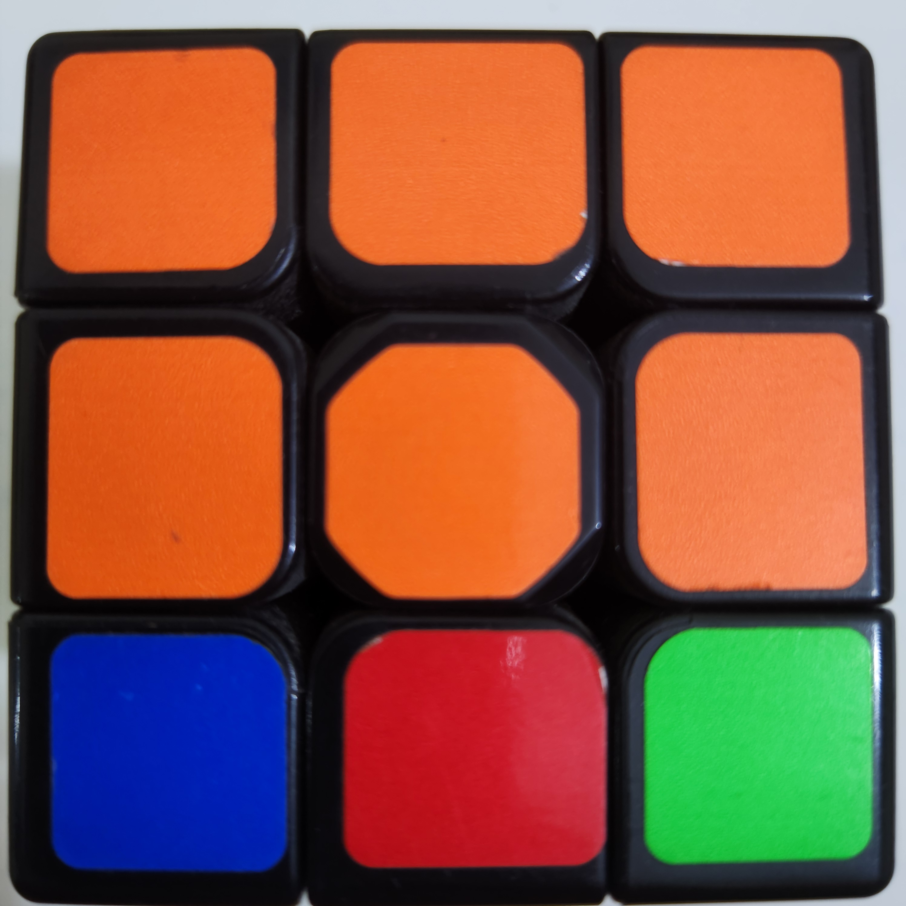
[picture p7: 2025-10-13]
backend/uploads/R.jpg

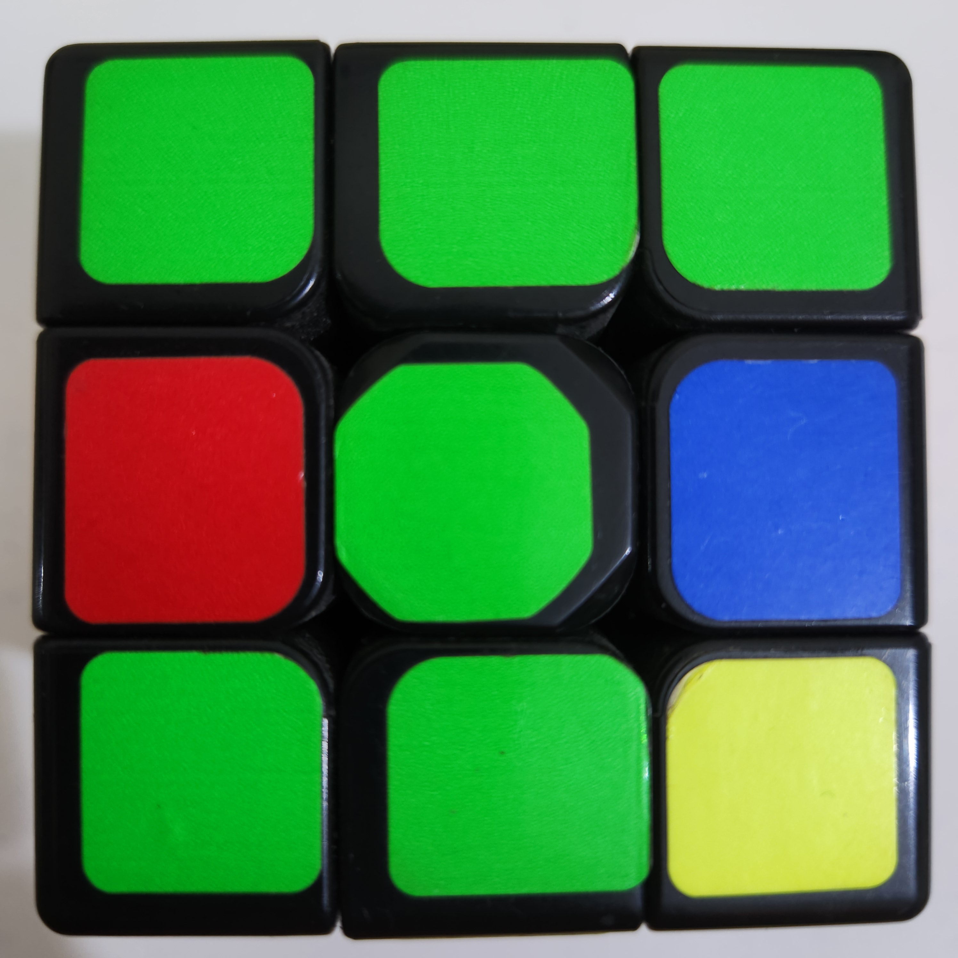
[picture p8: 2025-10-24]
backend/uploads/F.jpg

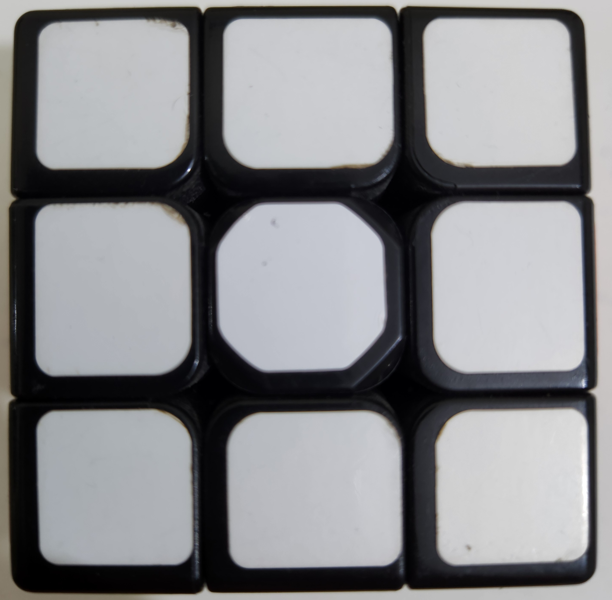
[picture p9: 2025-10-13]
backend/uploads/U.jpg

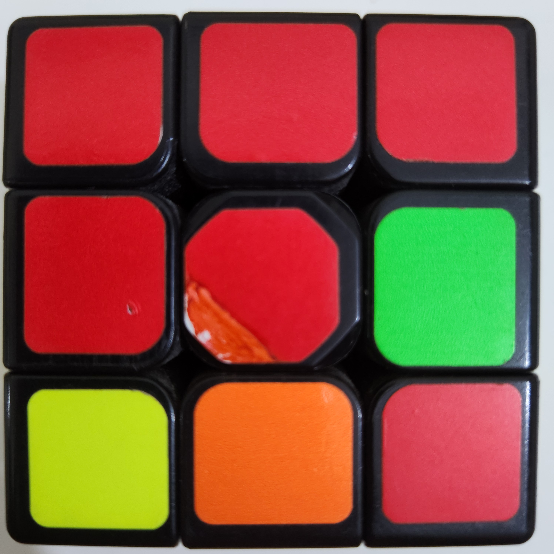
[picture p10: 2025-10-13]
backend/uploads/L.jpg

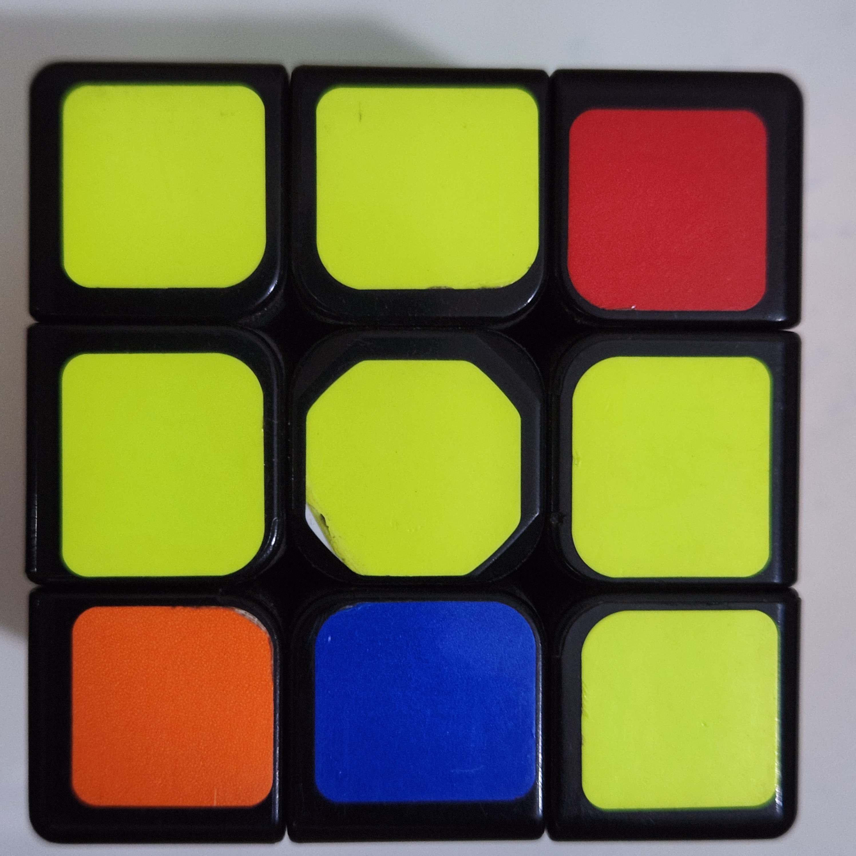
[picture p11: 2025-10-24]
backend/uploads/D.jpg

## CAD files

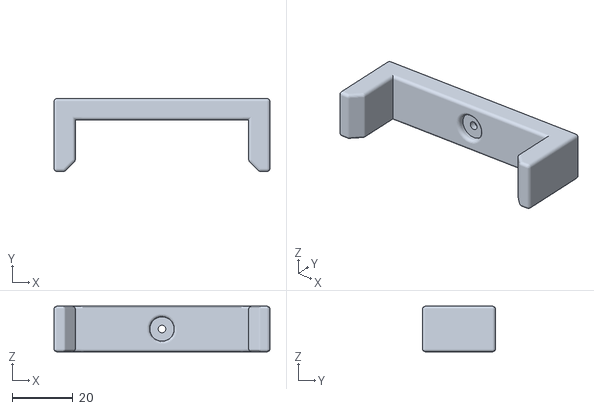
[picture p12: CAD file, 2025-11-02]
assets/3d_parts/clamp.stl
71.0 x 24.0 x 15.0

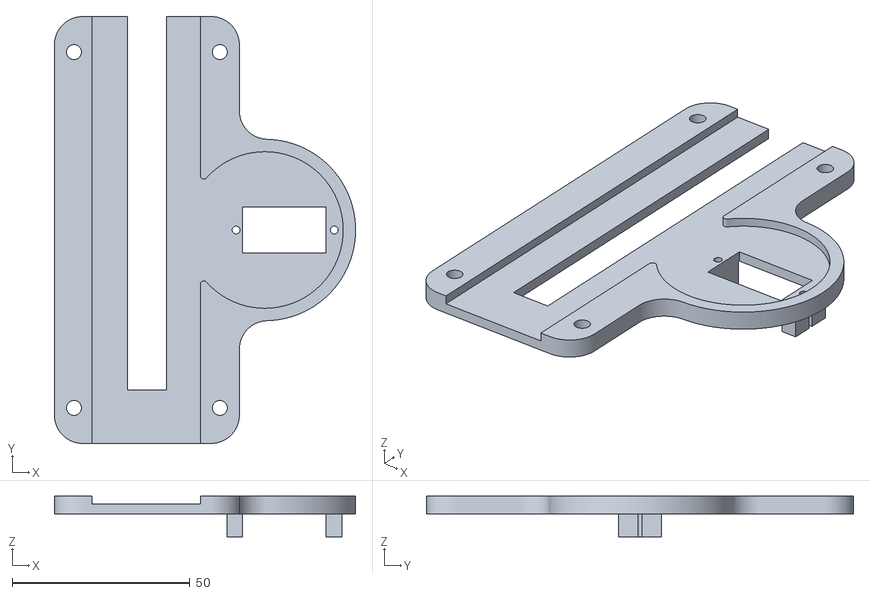
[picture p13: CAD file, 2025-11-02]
assets/3d_parts/rack top.stl
84.7 x 120.0 x 11.5

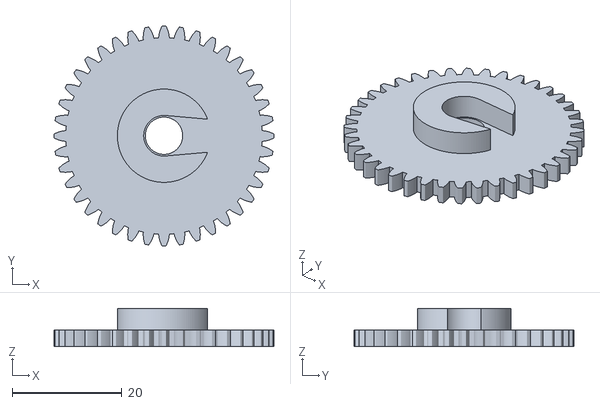
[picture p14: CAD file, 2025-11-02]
assets/3d_parts/spur gear.stl
40.1 x 40.1 x 7.00

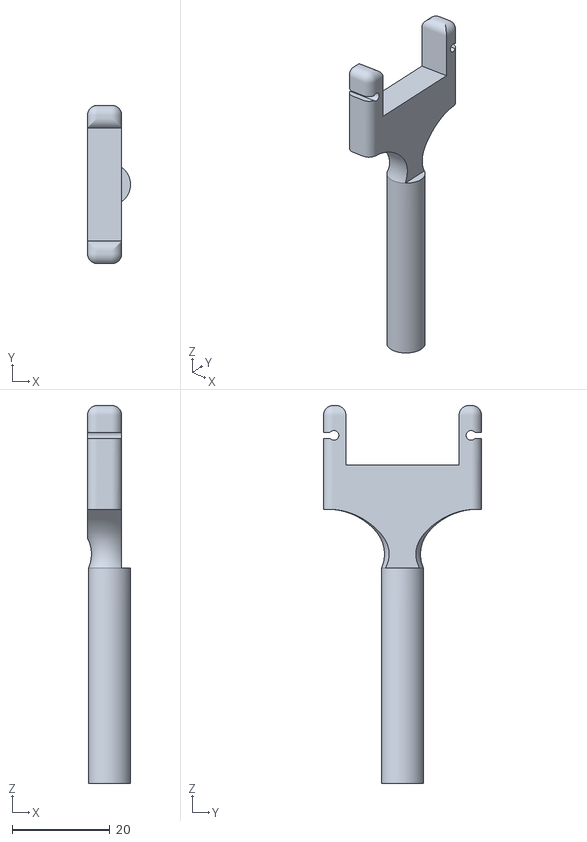
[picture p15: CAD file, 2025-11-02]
assets/3d_parts/servo holder.stl
8.80 x 32.3 x 77.2

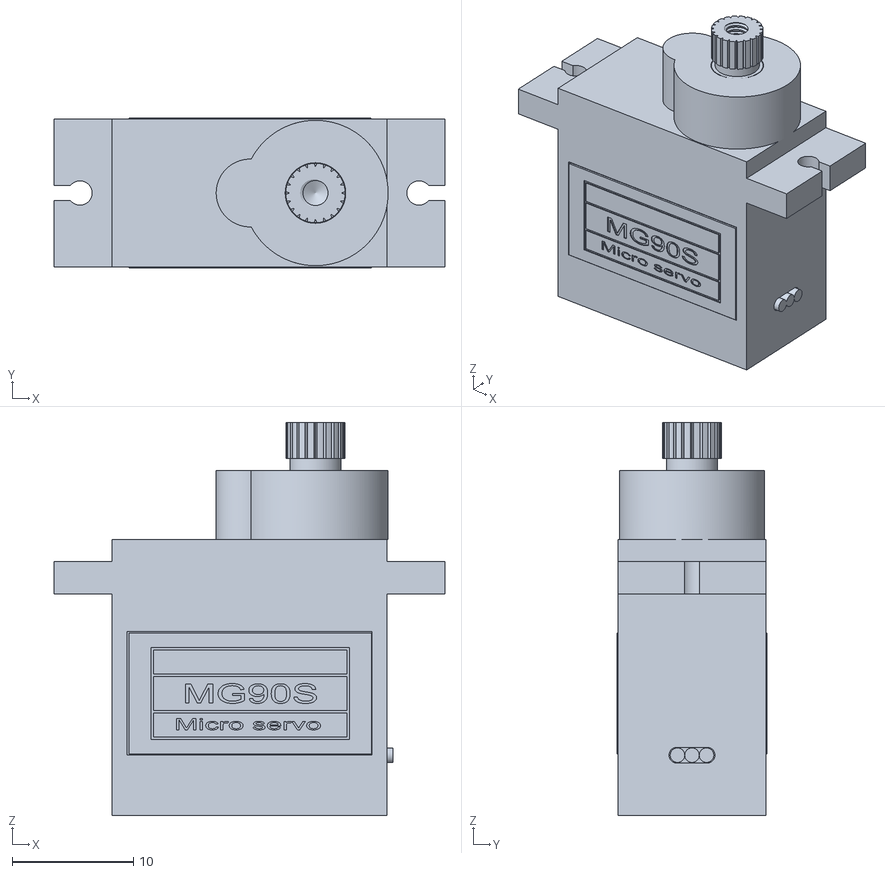
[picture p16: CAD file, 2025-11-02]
assets/3d_parts/M90S.stl
32.3 x 12.4 x 32.5

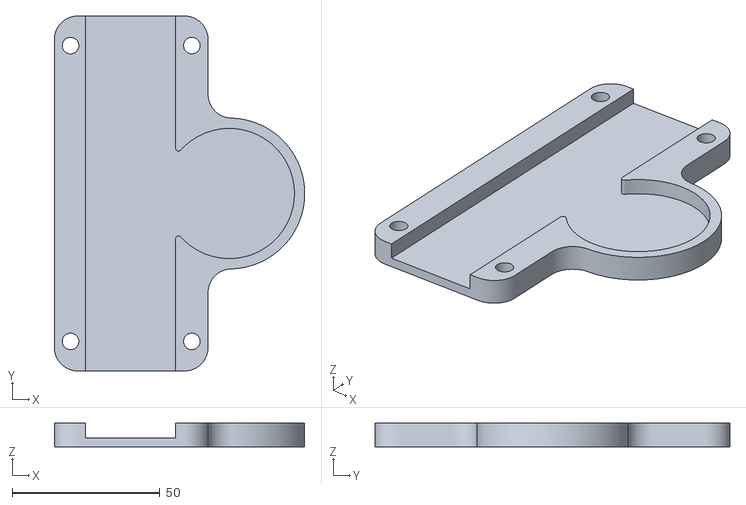
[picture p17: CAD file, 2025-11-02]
assets/3d_parts/rack base.stl
84.7 x 120.0 x 8.00

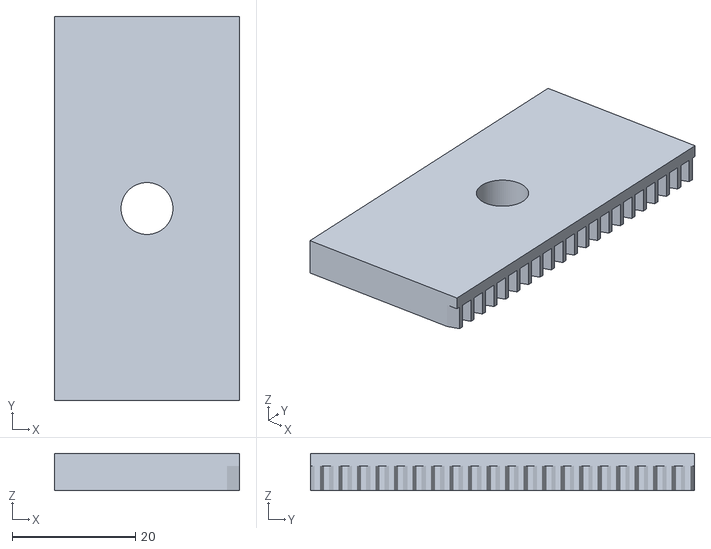
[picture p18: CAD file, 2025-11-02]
assets/3d_parts/rack.stl
30.0 x 62.2 x 6.00

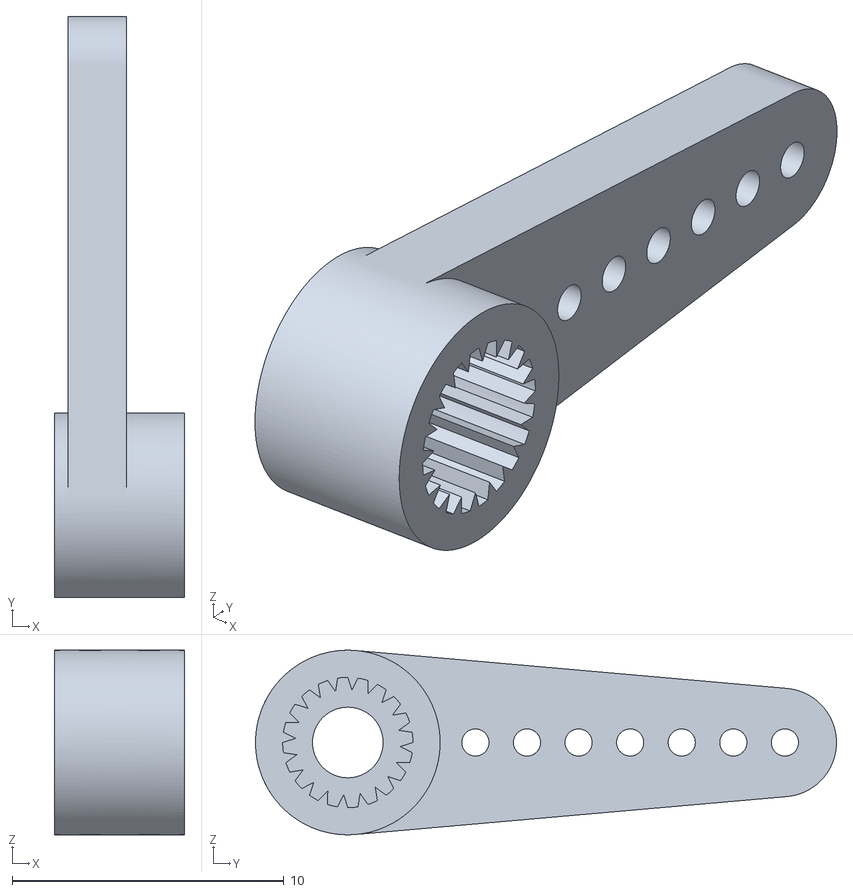
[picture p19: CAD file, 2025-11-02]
assets/3d_parts/MG90S_arm.stl
4.80 x 21.4 x 6.80

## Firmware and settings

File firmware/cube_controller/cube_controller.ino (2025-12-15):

#include <Arduino.h>
#include <ESP32Servo.h>
/*
    "F": "Rotate the Front face 90° clockwise",
    "F'": "Rotate the Front face 90° counter-clockwise",
    "F2": "Rotate the Front face 180° (half turn)",
    "B": "Rotate the Back face 90° clockwise",
    "B'": "Rotate the Back face 90° counter-clockwise",
    "B2": "Rotate the Back face 180°",
    "U": "Rotate the Up (top) face 90° clockwise",
    "U'": "Rotate the Up face 90° counter-clockwise",
    "U2": "Rotate the Up face 180°",
    "D": "Rotate the Down (bottom) face 90° clockwise",
    "D'": "Rotate the Down face 90° counter-clockwise",
    "D2": "Rotate the Down face 180°",
    "R": "Rotate the Right face 90° clockwise",
    "R'": "Rotate the Right face 90° counter-clockwise",
    "R2": "Rotate the Right face 180°",
    "L": "Rotate the Left face 90° clockwise",
    "L'": "Rotate the Left face 90° counter-clockwise",
    "L2": "Rotate the Left face 180°",
*/
// ---- Servo Objects ----
Servo baseFront, baseBack, baseLeft, baseRight;
Servo faceFront, faceBack, faceLeft, faceRight;

// ---- Servo Angles ----
int servoNeutral = 90;      // Neutral position for face servos
int servoCW = 180;          // Clockwise rotation
int servoCCW = 0;           // Counter-Clockwise rotation
int servoGrip = 0;          // Forward position (0°) - AUTO GRIPS
int servoRelease = 90;      // Backward position (90°) - AUTO RELEASES

// ---- Function Declarations ----
void executeMove(String move);
void resetFaceServos();
void moveBaseBack();
void moveBaseForward();

// ---- Setup ----
void setup() {
  Serial.begin(115200);
  delay(500);
  Serial.println("✅ ESP32 Cube Controller Ready");

  // Attach base servos
  baseFront.attach(13);
  baseBack.attach(12);
  baseLeft.attach(14);
  baseRight.attach(27);

  // Attach face servos
  faceFront.attach(26);
  faceBack.attach(25);
  faceLeft.attach(33);
  faceRight.attach(32);

  resetFaceServos();
  moveBaseBack();  // Start in release position
  Serial.println("🔵 Waiting for commands...");
}

// ---- Loop ----
void loop() {
  if (Serial.available()) {
    String input = Serial.readStringUntil('\n');
    input.trim();

    if (input.length() == 0) return;

    Serial.print("📥 Received: ");
    Serial.println(input);

    // Handle base position commands
    if (input == "BASE_BACK") {
      moveBaseBack();  // 90° - auto releases
      Serial.println("DONE");
    } 
    else if (input == "BASE_FORWARD") {
      moveBaseForward();  // 0° - auto grips
      Serial.println("DONE");
    }
    // Handle cube moves
    else if (input.startsWith("F") || input.startsWith("R") || 
             input.startsWith("L") || input.startsWith("B") || 
             input.startsWith("U") || input.startsWith("D")) {
      executeMove(input);
      resetFaceServos();
      Serial.println("DONE");  // ACK to ROS2
    } 
    else {
      Serial.println("⚠️ Unknown command: " + input);
      Serial.println("DONE");  // Still send ACK to prevent timeout
    }
  }
}

// ---- Base Movement Functions ----
// === release the cube ===
void moveBaseBack() {
  Serial.println("⬅️ Moving base backward (RELEASE)...");
  baseFront.write(servoRelease);
  baseBack.write(servoRelease);
  baseLeft.write(servoRelease);
  baseRight.write(servoRelease);
  delay(800);
}
// === grip the cube ===
void moveBaseForward() {
  Serial.println("➡️ Moving base forward (GRIP)...");
  baseFront.write(servoGrip);
  baseBack.write(servoGrip);
  baseLeft.write(servoGrip);
  baseRight.write(servoGrip);
  delay(800);
}

// ---- Reset Face Servos to Neutral on 90 degree ----
void resetFaceServos() {
  faceFront.write(servoNeutral);
  faceBack.write(servoNeutral);
  faceLeft.write(servoNeutral);
  faceRight.write(servoNeutral);
  delay(400);
}

// ==== Motion Logic ====
void executeMove(String move) {
  if (move == "F") rotateFrontCW();
  else if (move == "F'") rotateFrontCCW();
  else if (move == "F2") rotateFront180();
  else if (move == "R") rotateRightCW();
  else if (move == "R'") rotateRightCCW();
  else if (move == "R2") rotateRight180();
  else if (move == "L") rotateLeftCW();
  else if (move == "L'") rotateLeftCCW();
  else if (move == "L2") rotateLeft180();
  else if (move == "B") rotateBackCW();
  else if (move == "B'") rotateBackCCW();
  else if (move == "B2") rotateBack180();
  else if (move == "U") rotateUpCW();
  else if (move == "U'") rotateUpCCW();
  else if (move == "U2") rotateUp180();
  else if (move == "D") rotateDownCW();
  else if (move == "D'") rotateDownCCW();
  else if (move == "D2") rotateDown180();
  else Serial.println("⚠️ Unknown move: " + move);
}

// === Front Face 90° clockwise Rotations ===
void rotateFrontCW() {
  Serial.println("➡️ Front 90° CW");
  faceFront.write(servoCW);
  delay(800);
  baseFront.write(servoRelease);
  delay(800);
  faceFront.write(servoNeutral);
  delay(600);
  baseFront.write(servoGrip);
  delay(600);
}

// === Front Face 90° counter clockwise Rotations ===
void rotateFrontCCW() {
  Serial.println("⬅️ Front 90° CCW");
  faceFront.write(servoCCW);
  delay(800);
  baseFront.write(servoRelease);
  delay(800);
  faceFront.write(servoNeutral);
  delay(600);
  baseFront.write(servoGrip);
  delay(600);
}

// === Front Face 180° clockwise Rotations ===
void rotateFront180() {
  Serial.println("🔄 Front 90°+90° clockwise");
  
  // First 90° rotation
  rotateFrontCW();

  // Second 90° rotation
  rotateFrontCW();
}

// === Right Face 90° clockwise Rotations ===
void rotateRightCW() {
  Serial.println("➡️ Right 90° CW");
  faceRight.write(servoCW);
  delay(800);
  baseRight.write(servoRelease);
  delay(600);
  faceRight.write(servoNeutral);
  delay(600);
  baseRight.write(servoGrip);
  delay(600);
}

// === Right Face 90° counter clockwise Rotations ===
void rotateRightCCW() {
  Serial.println("⬅️ Right 90° CCW");
  faceRight.write(servoCCW);
  delay(800);
  baseRight.write(servoRelease);
  delay(600);
  faceRight.write(servoNeutral);
  delay(600);
  baseRight.write(servoGrip);
  delay(600);
}
// === Right Face 180° clockwise Rotations ===
void rotateRight180() {
  Serial.println("🔄 Right 180°");
  
  // First 90° rotation
  rotateRightCW();
  
  // Second 90° rotation
  rotateRightCW();
}

// === Left Face 90° clockwise Rotations ===
void rotateLeftCW() {
  Serial.println("➡️ Left 90° CW");
  faceLeft.write(servoCW);
  delay(800);
  baseLeft.write(servoRelease);
  delay(600);
  faceLeft.write(servoNeutral);
  delay(600);
  baseLeft.write(servoGrip);
  delay(800);
}

// === Left Face 90° counter clockwise Rotations ===
void rotateLeftCCW() {
  Serial.println("⬅️ Left 90° CCW");
  faceLeft.write(servoCCW);
  delay(800);
  baseLeft.write(servoRelease);
  delay(600);
  faceLeft.write(servoNeutral);
  delay(600);
  baseLeft.write(servoGrip);
  delay(800);
}

// === Left Face 180° clockwise Rotations ===
void rotateLeft180() {
  Serial.println("🔄 Left 180°");
  
  // First 90° rotation
  rotateLeftCW();
  
  // Second 90° rotation
  rotateLeftCW();
}

// === Back Face 90° clockwise Rotations ===
void rotateBackCW() {
  Serial.println("➡️ Back 90° CW");
  faceBack.write(servoCW);
  delay(800);
  baseBack.write(servoRelease);
  delay(600);
  faceBack.write(servoNeutral);
  delay(400);
  baseBack.write(servoGrip);
  delay(600);
}

// === Back Face 90° counter clockwise Rotations ===
void rotateBackCCW() {
  Serial.println("⬅️ Back 90° CCW");
  faceBack.write(servoCCW);
  delay(800);
  baseBack.write(servoRelease);
  delay(600);
  faceBack.write(servoNeutral);
  delay(400);
  baseBack.write(servoGrip);
  delay(600);
}

// === Back Face 180° clockwise Rotations ===
void rotateBack180() {
  Serial.println("🔄 Back 180°");
  
  // First 90° rotation
  rotateBackCW();
  
  // Second 90° rotation
  rotateBackCCW();
}

// ---- rotate up to front ----
void rotateUptoFront() {
  Serial.println("🔄 Up to front");
  // release right and left side
  baseFront.write(servoRelease);
  baseBack.write(servoRelease);
  delay(600);

  // now rotate the cube
  for (int i = 0; i <= 90; i+=5)
  {
    faceRight.write(servoNeutral - i);
    faceLeft.write(servoNeutral + i);
  }
  
  // Grip right and left side
  baseFront.write(servoGrip);
  baseBack.write(servoGrip);
}

// ---- Rotate Front face to Up face ----
void rotateFronttoUp() {
  Serial.println("🔄 front to up");
  // release Front and Back side
  baseFront.write(servoRelease);
  baseBack.write(servoRelease);
  delay(600);

  // now rotate the cube
  for (int i = 0; i <= 90; i+=5)
  {
    faceRight.write(servoNeutral + i);
    faceLeft.write(servoNeutral - i);
    delay(50);
  }

  // Grip Front and Back side
  baseFront.write(servoGrip);
  baseBack.write(servoGrip);
}

// === Up Face Rotations clockwise ===
void rotateUpCW() {
  Serial.println("⬆️ Up 90° CW");
  // Rotate Up face to Front face
  rotateUptoFront();

  // Rotate Front clockwise
  rotateFrontCW();

  // Rotate Front face to Up face
  rotateFronttoUp();
}

// === Up Face Rotations counter clockwise ===
void rotateUpCCW() {
  Serial.println("⬇️ Up 90° CCW");
  // Rotate Up face to Front face
  rotateUptoFront();

  // Rotate Front counter clockwise face
  rotateFrontCCW();

  // Rotate Front face to Up face
  rotateFronttoUp();
}

// === Up Face Rotations 180° ===
void rotateUp180() {
  Serial.println("🔄 Up 180°");
  // Rotate Up face to Front face
  rotateUptoFront();

  // Rotate Front 180°
  rotateFront180();

  // Rotate Front face to Up face
  rotateFronttoUp();
}

// ---- rotate down to front ----
void rotateDowntoFront() {
  Serial.println("🔄 Down to front");
  // release Front and Back side
  baseFront.write(servoRelease);
  baseBack.write(servoRelease);
  delay(600);

  // now rotate the cube
  for (int i = 0; i <= 90; i+=5)
  {
    faceRight.write(servoNeutral + i);
    faceLeft.write(servoNeutral - i);
    delay(50);
  }

  // Grip Front and Back side
  baseFront.write(servoGrip);
  baseBack.write(servoGrip);
}

// ---- Rotate Front face to Down face ----
void rotateFronttoDown() {
  Serial.println("🔄 front to down");

  // release right and left side
  baseFront.write(servoRelease);
  baseBack.write(servoRelease);
  delay(600);

  // now rotate the cube
  for (int i = 0; i <= 90; i+=5)
  {
    faceRight.write(servoNeutral - i);
    faceLeft.write(servoNeutral + i);
    delay(50);
  }
  // Grip right and left side
  baseFront.write(servoGrip);
  baseBack.write(servoGrip);
}

// === Down Face Rotations ===
void rotateDownCW() {
  Serial.println("⬇️ Down 90° CW");
  // Rotate Front face
  rotateDowntoFront();

  // Rotate Front clockwise
  rotateFrontCW();

  // Rotate Front face to Down face
  rotateFronttoDown();
}

// === Down Face Rotations counter clockwise ===
void rotateDownCCW() {
  Serial.println("⬆️ Down 90° CCW");
  // Rotate Down face to Front face
  rotateDowntoFront();

  // Rotate Front counter clockwise face
  rotateFrontCCW();

  // Rotate Front face to Down face
  rotateFronttoDown();
}

// === Down Face Rotations 180° ===
void rotateDown180() {
  Serial.println("🔄 Down 180°");
  // Rotate Down face to Front face
  rotateDowntoFront();

  // Rotate Front 180°
  rotateFront180();

  // Rotate Front face to Down face
  rotateFronttoDown();
}

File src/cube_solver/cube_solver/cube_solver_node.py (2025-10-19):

"""
cube_solver_node
=================

A ROS2 node that consumes a full Rubik's Cube solution string and streams
individual moves to an ESP32-based hardware controller over a serial link.

Responsibilities:
- Subscribe to a solution topic (std_msgs/String) carrying a space-separated
  sequence of cube moves (e.g., "R U R' U' F2").
- Send each move to the ESP32 on /dev/ttyUSB0 at 115200 baud, one per line.
- Wait for a per-move acknowledgment line "DONE" from the ESP32 before sending
  the next move; aborts on timeout or serial errors.
- Publish each move to a telemetry topic for UI/monitoring purposes.

Interfaces:
- Subscribes:  /cube_solution (std_msgs/msg/String)
- Publishes:   /cube_move    (std_msgs/msg/String)
- Serial port: /dev/ttyUSB0, 115200 baud, 1s read timeout; 10s total wait per move

Notes:
- The node logs connection status, incoming solutions, per-move progress,
  acknowledgments, and error conditions.
- BASE_FORWARD automatically grips cube (0°)
- BASE_BACK automatically releases cube (90°)
"""

import rclpy
from rclpy.node import Node
from std_msgs.msg import String
import serial
import time

class CubeSolverNode(Node):
    """
    ROS2 node that streams cube moves to an ESP32 with ACK handshaking.

    This node bridges high-level cube solutions to low-level actuator control
    by:
    - Listening for complete solution strings on the ``cube_solution`` topic.
    - Parsing the string into discrete moves.
    - Sending each move to an ESP32 over a serial connection.
    - Waiting for a ``DONE`` acknowledgment per move before proceeding.
    - Publishing each move on the ``cube_move`` topic for dashboards.

    Attributes
    ----------
    solution_sub : rclpy.subscription.Subscription
        Subscription to receive solution strings.
    move_pub : rclpy.publisher.Publisher
        Publisher emitting each move as it is sent to hardware.
    serial_port : serial.Serial | None
        Open serial connection to the ESP32, or ``None`` if unavailable.
    """
    def __init__(self):
        super().__init__('cube_solver_node')

        # ROS 2 interfaces: subscribe for solutions, publish each executed move.
        self.solution_sub = self.create_subscription(String, 'cube_solution', self.solution_callback, 10)
        self.move_pub = self.create_publisher(String, 'cube_move', 10)

        # Establish serial connection to the ESP32 controller.
        # Port and baud rate must match firmware settings.
        try:
            self.serial_port = serial.Serial('/dev/ttyUSB0', 115200, timeout=1)
            self.get_logger().info("✅ Connected to ESP32 on /dev/ttyUSB0")
        except Exception as e:
            self.serial_port = None
            self.get_logger().error(f"❌ Could not connect to ESP32: {e}")

        self.get_logger().info("Cube Solver Node started, waiting for solutions...")

    def solution_callback(self, msg):
        """
        Process an incoming cube solution string with pre/post setup sequences.
        """
        solution = msg.data.strip()
        moves = solution.split()

        self.get_logger().info(f"Received solution: {solution}")
        self.get_logger().info(f"Parsed {len(moves)} moves.")

        # === INITIAL SETUP SEQUENCE ===
        self.get_logger().info("🔧 Preparing cube holder...")
        self.send_move_with_ack("BASE_BACK")     # Release position (90°)
        time.sleep(3)
        self.send_move_with_ack("BASE_FORWARD")  # Grip position (0° - auto grips)
        time.sleep(3)
        self.get_logger().info("✅ Cube secured, starting solve sequence.")

        # === MAIN SOLVE LOOP ===
        for move in moves:
            success = self.send_move_with_ack(move)
            if not success:
                self.get_logger().warn(f"⚠️ No ACK for move '{move}', stopping sequence.")
                break

        # === POST-SOLVE CLEANUP ===
        self.get_logger().info("🎉 Solve sequence complete. Releasing cube...")
        self.send_move_with_ack("BASE_BACK")     # Release position (90° - auto releases)
        time.sleep(2)

        self.get_logger().info("✅ All steps finished successfully.")

    def send_move_with_ack(self, move):
        """
        Send one move to the ESP32 and wait for a ``DONE`` acknowledgment.

        The move is written to the serial port followed by a newline. The
        method then polls the serial buffer for up to 10 seconds awaiting a
        line equal to ``DONE``. Any other lines are logged at INFO level.

        Parameters
        ----------
        move : str
            A single cube move token (e.g., "R", "U'", "F2").

        Returns
        -------
        bool
            ``True`` if a ``DONE`` acknowledgment was received within the
            timeout; ``False`` if the serial port is unavailable, an error
            occurs, or the ACK times out.
        """
        if not self.serial_port:
            self.get_logger().warn("⚠️ ESP32 not connected.")
            return False

        try:
            # Send move
            self.serial_port.write((move + '\n').encode('utf-8'))
            self.get_logger().info(f"📤 Sent to ESP32: {move}")

            # Publish move (for dashboard)
            self.move_pub.publish(String(data=move))

            # Wait for acknowledgement
            start_time = time.time()
            while time.time() - start_time < 10:  # 10s timeout
                if self.serial_port.in_waiting > 0:
                    line = self.serial_port.readline().decode('utf-8').strip()
                    if line == "DONE":
                        self.get_logger().info(f"✅ ACK received for move: {move}")
                        return True
                    else:
                        self.get_logger().info(f"ESP32 says: {line}")
                time.sleep(0.1)

            self.get_logger().error(f"❌ Timeout waiting for ACK for move: {move}")
            return False

        except Exception as e:
            self.get_logger().error(f"⚠️ Serial communication error: {e}")
            return False

def main(args=None):
    """
    Entry point: initialize ROS, run the node, and ensure clean shutdown.

    This function initializes the rclpy context, creates and spins the
    ``CubeSolverNode`` until interrupted, then closes the serial port (if open),
    destroys the node, and shuts down rclpy.
    """
    rclpy.init(args=args)
    node = CubeSolverNode()
    try:
        rclpy.spin(node)
    except KeyboardInterrupt:
        pass
    finally:
        # Close serial port explicitly to release the device handle on exit.
        if node.serial_port:
            node.serial_port.close()
        node.destroy_node()
        rclpy.shutdown()

if __name__ == '__main__':
    main()

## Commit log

2025-10-13 feat: Initial implementation of Rubik's Cube Solver Dashboard
    - Added frontend components including HTML, CSS, and JavaScript for the dashboard.
    - Implemented form submission prevention and backend IP configuration.
    - Integrated file upload functionality for cube face images.
    - Developed real-time camera capture and upload features.
    - Created color correction interface for manual adjustments.
    - Established backend connection handling and solution retrieval.
    - Introduced ROS node for cube solution handling.
    - Set up package structure and configuration for the cube_solver package.
    - Included tests for copyright, flake8, and PEP257 compliance.
    [cube_solver_node.py]
2025-10-16 feat: Implement Cube Solver Node and ESP32 Controller for Rubik's Cube moves - add ESP32 code inside firmware - add cube_solver_node documentation
2025-10-16 feat: Reintroduce ESP32 Serial Listener for Rubik’s Cube Solver with move processing
2025-11-02 Add comprehensive API documentation for Flask backend
    - Documented the overall architecture and key components of the Flask app.
    - Detailed API endpoints for static file serving, cube solving workflow, and manual overrides.
    - Included configuration settings, deployment instructions, error handling, and security notes.
    - Provided example workflows and testing guidelines for unit and integration tests.
    - Added changelog and contributing guidelines for future development.
    [M90S.stl, MG90S_arm.stl, clamp.stl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]
2025-12-15 refactor: Simplify rotation functions and improve servo control logic in cube_controller.ino

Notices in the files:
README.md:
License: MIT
